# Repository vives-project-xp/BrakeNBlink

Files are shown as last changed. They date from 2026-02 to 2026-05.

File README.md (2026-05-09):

# BrakeNBlink
Brake N Blink is een (semi) automatisch rem en richtingaanwijzersysteem voor fietsen dat
de zichtbaarheid en veiligheid van fietsers verhoogt. Het detecteert automatisch via een IMU/Knoppen of de fietser remt/gaat afslaan en stuurt zo de remlichten en richtingaanwijzers aan.

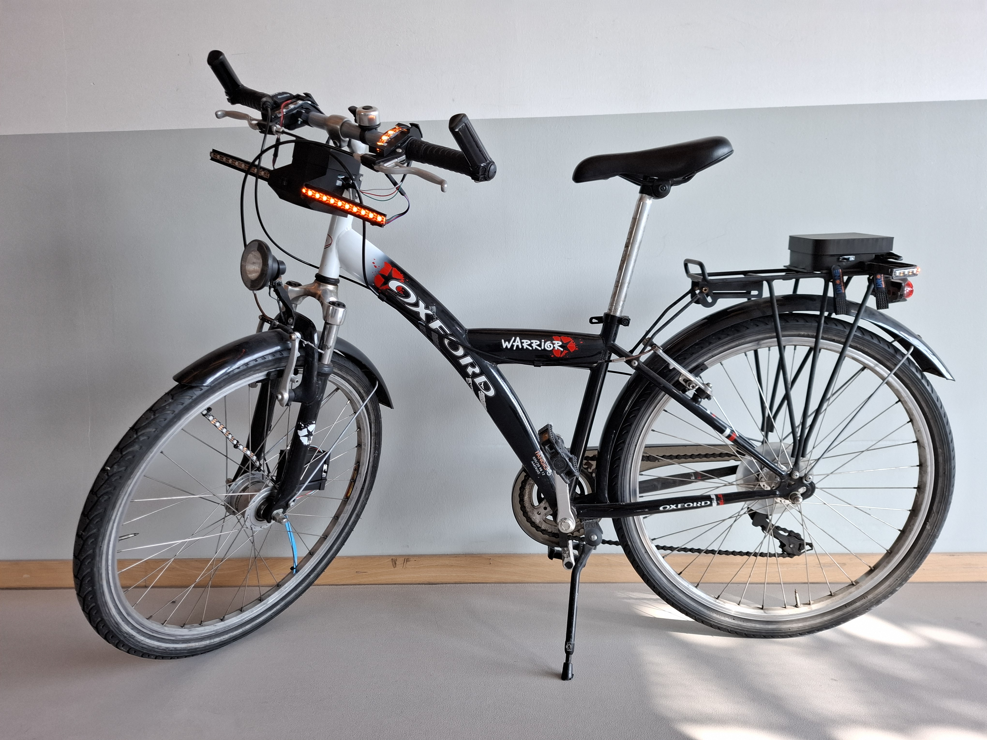
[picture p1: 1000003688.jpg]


---

## Doel van het project
Fietsers behoren tot kwetsbare weggebuikers, vooral in steden of omgevingen met een beperkte zichtbaarheid. Brake N Blink verhoogt de zichtbaarheid (zeker s'nachts) van de fietser voor andere weggebruikers.

---
## Product

### Vooraan
Drukknoppen voor de linker- en rechterrichtingaanwijzer, verbonden via Bluetooth met de achterste controlemodule. Eigen batterijvoorziening.

### Achteraan
Achteraan zit een microcontroller die het remlicht aanstuurt op basis van de interne IMU. De richtingaanwijzers worden bediend via een stuurmodule die draadloos verbonden is via Bluetooth.

### Uitbreiding
Led strips in de spaken via een microcontroller met interne batterij. Specifiek hebben we twee LED-strips tegenover elkaar gemonteerd op het voorwiel van de fiets. Deze strips produceren verschillende lichtpatronen, aangestuurd door een microcontroller, om de zichtbaarheid en esthetiek van de fiets te verbeteren.

### Gebruikershandleiding
Hier vindt u de [gebruikershandleiding](Documentatie/Gebruikershandleiding/) met instructies voor het gebruik en onderhoud van het BrakeNBlink-systeem.

---
## Project Management

Wij maken gebruik van Trello voor de sprintplanning en issue tracking.

---

## Reflectie

Tijdens dit project hebben we veel geleerd over het ontwerpen en implementeren van een elektronisch systeem voor fietsen. We hebben ervaring opgedaan met het gebruik van microcontrollers, Bluetooth-communicatie en het integreren van verschillende componenten zoals LED-strips en drukknoppen. We hebben ook geleerd hoe we een project kunnen structureren en documenteren, wat belangrijk is voor samenwerking en toekomstige referentie.

Hoewel we enkele uitdagingen tegenkwamen, zoals het optimaliseren van de Bluetooth-verbinding en het ontwerpen van een sterke en functionele behuizing. We hebben deze problemen opgelost door middel van trial and error. Al met al heeft dit project ons waardevolle vaardigheden en inzichten opgeleverd die we in toekomstige projecten kunnen toepassen.

---

## Repository structuur

- 📁 **[3D model behuizing/](3D%20model%20behuizing/)**: Bevat 3D-modellen voor de behuizing van het systeem, inclusief Blender-bestanden en 3MF-bestanden voor 3D-printing.
- 📁 **[Documentatie/](Documentatie/)**: Omvat alle documentatie gerelateerd aan het project.
  - 📁 **[Datasheets & Materiaal lijst/](Documentatie/Datasheets%20%26%20Materiaal%20lijst/)**: Datasheets, materiaaloverzichten en informatie over componenten zoals batterijhouders, bedrading, drukknoppen, LED-strips, microcontroller (Arduino), printplaten en batterijen.
  - 📁 **[Gids/](Documentatie/Gids/)**: Handleidingen, zoals de GitHub-gids.
  - 📁 **[Gebruikershandleiding/](Documentatie/Gebruikershandleiding/)**: Gebruikershandleiding voor het systeem.
  - 📁 **[Knoppen/](Documentatie/Knoppen/)**: Documentatie over de drukknoppen.
  - 📁 **[Overzichten/](Documentatie/Overzichten/)**: Overzichten van materialen, inclusief specifieke informatie over drukknoppen.
  - 📁 **[Voorstellingen/](Documentatie/Voorstellingen/)**: Sprekersnotities voor presentaties.
- 📁 **[Poster/](Poster/)**: Bevat de projectposter.
- 📁 **[Prototypes and simulations/](Prototypes%20and%20simulations/)**: Code en schema's voor prototypes en simulaties.
  - 📁 **[Eerste versie op breadboard/](Prototypes%20and%20simulations/Eerste%20versie%20op%20breadboard/)**: Eerste prototype op breadboard met Arduino-code.
  - 📁 **[Eindresultaat/](Prototypes%20and%20simulations/Eindresultaat/)**: Finale prototypes, inclusief LED-strips en normale LEDs met Bluetooth-functionaliteit.
  - 📁 **[Led strip Test/](Prototypes%20and%20simulations/Led%20strip%20Test/)**: Testcode voor LED-strips.
  - 📁 **[Prototype Gyro/](Prototypes%20and%20simulations/Prototype%20Gyro/)**: Prototype met gyroscoop.
  - 📁 **[Prototype Remlicht/](Prototypes%20and%20simulations/Prototype%20Remlicht/)**: Prototype voor remlicht.
  - 📁 **[Top Down Schema's/](Prototypes%20and%20simulations/Top%20Down%20Schema%27s/)**: Top-down schema's voor prototypes, master, slave en uitbreidingen.
  - 📁 **[Uitbreiding/](Prototypes%20and%20simulations/Uitbreiding/)**: Uitbreidingen voor het systeem, inclusief extra LEDs.
- 📁 **[Sociale media/](Sociale%20media/)**: Afbeeldingen en media voor sociale media, inclusief 3D-printing, prototypes op de fiets en solderen.

## Team
dit project is gemaakt door:

- **Tom Pladijs** - fase 2, Elektronica
- **Timo Sinnaeve** - fase 1, Elektronica ICT
- **Aaron Lestarquit** - fase 1, Elektronica ICT

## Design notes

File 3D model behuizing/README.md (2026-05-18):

# BrakeNBlink - 3D Modellering Behuizing

## Projectoverzicht

Dit project bevat de volledige 3D-modellering voor de behuizing van **BrakeNBlink**. De modellen zijn ontworpen in Blender en geoptimaliseerd voor 3D-printing. In de uitbreiding folder, vind je de bestanden voor de uitbreiding.

**BrakeNBlink** bestaat uit drie delen + uitbreiding:
- **Voorkant**: bevat de elektronica en richtingaanwijzers
- **Achterkant**: ook elektronica met richtingaanwijzers en achterlicht
- **Stuur**: knoppen om richtingaanwijzers aan te zetten met een korte richtingaanwijzer ledstrip.
- **Uitbreiding**: extra zichbaarheid aan het wiel

---

## Gebruikte modelling software

- **Blender** 4.3.2 - 3D modellering en design
- **Formaat**: .blend & .blend1 (Blender native format)
- **Export formaat**: .stl voor 3D-printing

---

## Mappenstructuur

```
3D model behuizing/
├── BrakeNBlink Behuizing.blend     # Blender hoofdbestand
├── README.md                          # Dit bestand
├── 3D Print Files/                    
│   ├── Voorkant/                      # Behuizing voorkaant
│   ├── Achterkant/                    # Behuizing achterkant
│   └── Stuur/                         # Behuizing op het stuur
│   └── README_3D_Print.md         # Print instellingen
└── Uitbreiding/                       # Deel aan het wiel
```

---

## Blender Bestandsstructuur
- afgemeten componenten: wordt gebruikt als referentie om de behuizing te maken.
- Assembly: montage van alles op de fiets, puur visueel
- Moddeling: hierin worden de behuizing aangepast en verbeterd
- Om te 3D printen: bestanden klaar voor export naar .stl


---

## 3D-Printbare Onderdelen

Alle printbare onderdelen bevinden zich in de `3D Print Files/` map. Elk onderdeel is afzonderlijk beschikbaar als `.stl`-bestand:

---

## Montage

---

### bestanden in Blender aanpassen:
1. Open `BrakeNBlink Behuizing.blend` in Blender
2. Selecteer de collectie die je wilt wijzigen
3. Maak de gewenste wijzigingen
4. Exporteer naar `.stl` via: **File > Export > .stl**

---

### Benodigde hardware voor installatie
- M4 bouten en moeren

---

## Ondersteuning & Opmerkingen

- Voor vragen over de modellering: raadpleeg het Blender-bestand
- Voor printinstellingen: zie `3D Print Files/README_3D_Print.md`

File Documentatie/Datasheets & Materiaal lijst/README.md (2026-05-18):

# BrakeNBlink — Architectuur Document

## 1. Projectoverzicht

BrakeNBlink is een semi-automatisch rem- en richtingaanwijzersysteem voor fietsen. Het systeem bestaat uit twee modules: een **achtermodule** (Peripheral) die remlichten en richtingaanwijzers aanstuurt, en een **stuurmodule** (Central) met drukknoppen voor de richtingaanwijzers. De twee modules communiceren draadloos via Bluetooth Low Energy (BLE).

Optioneel is er een **uitbreidingsmodule** met LED-strips in de spaken van het wiel.

---

## 2. Systeemoverzicht

```
[ Stuurmodule (Central) ]
   - Arduino Nano 33 BLE Sense Rev2
   - 2x Drukknop
   - 2x LED strip (richtingaanwijzer links/rechts)
   - Batterij (3 x AAA)
          |
          | Bluetooth Low Energy (BLE)
          |
[ Achtermodule (Peripheral) ]
   - Arduino Nano 33 BLE Sense Rev2
   - IMU ingebouwd (BMI270 + BMM150)
   - 3x LED strip (links / rechts / rem)
   - Batterij (3 x AAA)

[ Uitbreidingsmodule (optioneel) ]
   - Arduino Nano 33 BLE Sense Rev2
   - 2x LED strip (spaken)
   - IMU (snelheidsmeter)
   - Batterij (3 x AA)
```

---

## 3. Componenten

### 3.1 Microcontroller — Arduino Nano 33 BLE Sense Rev2

| Eigenschap | Waarde |
|---|---|
| Voedingsspanning | 3.3 V (logica) / 5 V (USB / VIN) |
| Max stroom per I/O pin | 15 mA |
| Aanbevolen VIN | 5 – 21 V |
| BLE | Bluetooth 5.0 |
| IMU | BMI270 (accel/gyro) + BMM150 (mag)  |
| Afmetingen | 45 × 18 mm |
| Verbruik actief | 60 mA |
| Verbruik BLE actief | 70 mA |
| Max vermogen | 0.35 W |

> Wordt gebruikt in: Stuurmodule (Central), Achtermodule (Peripheral) en Uitbreidingsmodule.

---

### 3.2 LED Strip — SK6812 RGBW

| Eigenschap | Waarde |
|---|---|
| Voedingsspanning | 5 V DC |
| Stroom per LED (volledig)| 80 mA |
| Max stroom (16 LEDs) | 1280 mA |
| Max vermogen (16 LEDs) | 6.4 W |
| Kleur | RGB + Natuurlijk Wit |
| Waterdichtheid | IP65 |
| Dataprotocol | NeoPixel (800 kHz) |
| Logicaspanning data | 5 V (3.3 V compatibel via niveau-omzetter) |

**Aansluitingen:**

| Strip-pin | Kleur draad | Aansluiting |
|---|---|---|
| 5V / VCC  | Rood | 5 V (via BEC of externe voeding) |
| GND | Wit | GND |
| DIN | Groen | Digitale pin Arduino (zie module) |
| DO | — | DIN van de volgende LED / strip |

> Elke LED geeft de resterende data door via DO → DIN van de volgende LED.

---

### 3.3 Drukknop (2-pin mechanisch)

| Eigenschap | Waarde |
|---|---|
| Type | Mechanische drukknop, 2-pin |
| Standaard toestand | HOOG (INPUT_PULLUP actief) |
| Ingedrukt | Verbonden met GND → LAAG |
| Max spanning | 12 V |
| Max stroom | 100 mA |
| Debounce tijd (code) | 150 ms |

**Aansluitingen:**

| Knop-pin | Aansluiting Arduino |
|---|---|
| Pin 1 | GND |
| Pin 2 | Digitale pin (D2 of D3) met INPUT_PULLUP |

---

### 3.4.1 Batterij — 3 × AAA 

| Eigenschap | Stuurmodule | Achtermodule |
|---|---|---|
| Aantal cellen | 3 × AAA | 3 × AAA |
| Nominale spanning | 4.5 V | 4.5 V |
| Capaciteit | 3000 mAh | 3000 mAh | 
| Max ontlaadstroom | 1.5 A | 1.5 A |

### 3.4.2 Batterij — 3 × AA 

| Eigenschap | Uitbreidingsmodule |
|---|---|
| Aantal cellen | 3 × AA |
| Nominale spanning | 4.5 V |
| Capaciteit | 2400 mAh |

---

### 3.5 Verbindingskabel — JST-SM 3-pin Verlengkabel

| Eigenschap | Waarde |
|---|---|
| Lengte | 30 cm |
| Pinnen | 3 |
| Type | JST-SM Compatibel |
| Gebruik | Aansluiting batterijhouder |

---

## 4. Pin-mapping per module

### 4.1 Stuurmodule (Central) — Arduino Nano 33 BLE Sense Rev2

| Pin | Functie | Component |
|-----|---|---|
| D2  | Knop Links (INPUT_PULLUP) | Drukknop Links |
| D3  | Knop Rechts (INPUT_PULLUP) | Drukknop Rechts |
| D4  | LED strip Links (DIN) | SK6812 strip Links |
| D5  | LED strip Rechts (DIN) | SK6812 strip Rechts |
| 5V  | Voeding LED strips | SK6812 via BEC / extern |
| GND | Ground | Alle componenten |
| VIN | Voeding vanuit batterij | Batterijhouder |

> BLE rol: **Central** — scant en verbindt met de Peripheral.

---

### 4.2 Achtermodule (Peripheral) — Arduino Nano 33 BLE Sense Rev2

| Pin | Functie | Component |
|---|---|---|
| D2 | LED strip Links (DIN) | SK6812 strip Links |
| D3 | LED strip Rechts (DIN) | SK6812 strip Rechts |
| D4 | LED strip Remlicht (DIN) | SK6812 strip Remlicht |
| IMU intern  | Versnellingsmeting X-as (ax) | BMI270 (ingebouwd) |
| IMU intern  | Kantelmeting lean angle (by, bz)  | BMI270 (ingebouwd) |
| 5V | Voeding LED strips | SK6812 via BEC / extern |
| GND | Ground | Alle componenten |
| VIN | Voeding vanuit batterij | Batterijhouder |

> BLE rol: **Peripheral** — adverteert als `"Nano 33 BLE Peripheral"`.  
> IMU drempel remmen: `ax < -0.20 g` → remlicht aan.  
> IMU drempel blinker auto-uit: kanteling `> 10°`, terugkeer `< 2°`.

---

### 4.3 Uitbreidingsmodule (spaken) — Arduino Nano 33 BLE Sense Rev2

| Pin | Functie | Component |
|---|---|---|
| D2 | LED strip A (DIN) | SK6812 strip Spaak A |
| D3 | LED strip B (DIN) | SK6812 strip Spaak B |
| IMU intern | Snelheidsmeting | BMI270 (ingebouwd) |
| 5V | Voeding LED strips | SK6812 via extern |
| GND | Ground | Alle componenten |
| VIN | Voeding vanuit batterij | Eigen batterij |

---

## 5. Bluetooth communicatie

| Eigenschap | Waarde |
|---|---|
| Protocol | Bluetooth Low Energy (BLE 5.0) |
| Service UUID | `19b10000-e8f2-537e-4f6c-d104768a1214` |
| Characteristic UUID  | `19b10001-e8f2-537e-4f6c-d104768a1214` |
| Peripheral naam | `"Nano 33 BLE Peripheral"` |
| Datatype | Byte (1 byte per commando) |

**Stuurcommando's (byte-waarden):**

| Byte waarde | Actie |
|---|---|
| `1` | Toggle linker richtingaanwijzer |
| `3` | Toggle rechter richtingaanwijzer |

---

## 6. Vermogensverdeling & elektriciteitsbudget

### 6.1 Stuurmodule

| Component | Spanning (V) | Stroom (mA) | Vermogen (W) |
|---|---|---|---|
| Arduino Nano 33 BLE | 3.3 / 5 | 65 | 0.21 |
| LED strip Links (16×) | 5 | 1280 | 6.4 |
| LED strip Rechts (16×)  | 5 | 1280 | 6.4 |
| Drukknop Links | 3.3 | ≈ 0 | ≈ 0 |
| Drukknop Rechts | 3.3 | ≈ 0 | ≈ 0 |
| **Totaal** | | 2625 | 13.01 |

### 6.2 Achtermodule

| Component | Spanning (V) | Stroom (mA) | Vermogen (W) |
|---|---|---|---|
| Arduino Nano 33 BLE | 3.3 / 5 | 65 | 0.21 |
| LED strip Links (16×) | 5 | 1280 | 6.4 |
| LED strip Rechts (16×)  | 5 | 1280 | 6.4 |
| LED strip Rem (16×) | 5 | 1280 | 6.4 |
| **Totaal** | | 3905 | 19.41 |

### 6.3 Uitbreidingsmodule

| Component | Spanning (V) | Stroom (mA) | Vermogen (W) |
|---|---|---|---|
| Arduino Nano 33 BLE | 3.3 / 5 | 65 | 0.21 |
| LED strip A (16×) | 5 | 1280 | 6.4 |
| LED strip B (16×) | 5 | 1280 | 6.4 |
| **Totaal** | | 2625 | 12.81 |

---

## 7. Softwarebiblioteken

| Bibliotheek | Versie | Gebruik |
|---|---|---|
| ArduinoBLE | 1.2.0 | Bluetooth Low Energy communicatie |
| Adafruit NeoPixel | 1.10.0 | SK6812 LED strip aansturing |
| Arduino_BMI270_BMM150  | 1.0.2 | IMU (accelerometer / gyroscoop) |

---

## 8. IMU logica

### Remdetectie (Achtermodule)
| Parameter | Waarde |
|---|---|
| Gemeten as | Lineaire versnelling X-as (ax)  |
| Drempelwaarde | `ax < -0.20 g` |
| Actie | Remlicht aan (rood) |
| Updatefrequentie  | Elke 10 ms |

### Richtingaanwijzer automatisch uit (Achtermodule)
| Parameter | Waarde |
|---|---|
| Berekening | `leanAngle = abs(atan2(by, bz) × 180 / π)` |
| Bocht gedetecteerd | `leanAngle > 10°` |
| Bocht voltooid | `leanAngle < 2°` (nadat de fiets geleund was)  |
| Actie | Blinker automatisch uit, LEDs uit |

---

## 9. Gedragsoverzicht

| Situatie | Actie systeem |
|---|---|
| Fietser remt | IMU detecteert vertraging → remlicht aan (rood) |
| Knop links ingedrukt | Linker LED strip knippert oranje (500 ms interval) |
| Knop links opnieuw ingedrukt | Linker richtingaanwijzer uit |
| Knop rechts ingedrukt | Rechter LED strip knippert oranje |
| Bocht voltooid (lean detected) | Blinker automatisch uit |
| Geen Bluetooth verbinding | Verbindings-LED uit, herverbinding automatisch |

---

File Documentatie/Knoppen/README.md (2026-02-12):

# Knoppen

2 knoppen zijn gemonteerd op het stuur van de fiets (links en rechts) en worden gebruikt om de richtingaanwijzers aan te sturen. De fietser klikt op een van de knoppen kort waardoor die richtingaanwijzer aan gaat. Ze gaan automatisch uit als de fiets weer rechtdoor rijdt of als er een tweede keer word geklikt. 

# Type knoppen:

## 1. 2-pin knoppen


Dit zijn mechanische knoppen met 2 pins:
- als je niks doet -> circuit is open
- als je klikt -> twee pins zijn verbonden

Standaard staat die op HOOG, als je klikt komt het circuit in verbinding met de GND, waardoor het op LAAG staat.

Wiring van een 2 pin knop:
- Pin 1: GND
- Pin 2: Digitale pin (bv. D2)

Nadeel van 2-pin knoppen: ze switchen niet mooi, niet waterdicht en wanneer er gedrukt wordt, gaan ze open en dicht heel snel voor een paar milliseconden. Dit wordt "bounce" genoemd. Hierdoor kan het zijn dat er meerdere keren "geklikt" wordt. Om dit te fixen kan je best een kleine delay toevoegen met wanneer de laatste keer geklikt werd.

## 2. Tactile push knoppen


Dezelfde werking als 2-pin knoppen, als je erop klikt is het circuit verbonden. Standaard staat die op HOOG, als je klikt komt het circuit in verbinding met de GND, waardoor het op LAAG staat. Het heeft 4 pins:
- Pin 1 en Pin 3 zijn intern verbonden
- Pin 2 en Pin 4 zijn intern verbonden

Wiring van Tactile knop:
- Pin 1 → GND
- Pin 2 → D2
- Pin 3 → niet verbonden
- Pin 4 → niet verbonden

Nadelen:  Niet goed voor vibraties en vaak ook niet waterdicht. 

# 3. SPDT center off switch / slide switch SPDT


een 3 switch knop, waarbij er 3 mogelijk positie's zijn. links, midden en rechts. Wordt gebruikt op de meeste motors en dus daardoor bekend. Handig als de fietser de button naar een kant duwt voor bv. de linkerrichtingaanwijzers aan te steken. Er kan altijd maar 1 richtingaanwijzer aan en de fietser kan zelf kiezen om het te stoppen. LOW -> Active

Layout:
- Links - Midden (uit) - Rechts

Wiring:
- Links -> 1ste digitale pin (Bv. D1)
- Common -> GND
- Rechts -> 2de digitale pin (Bv. D2)

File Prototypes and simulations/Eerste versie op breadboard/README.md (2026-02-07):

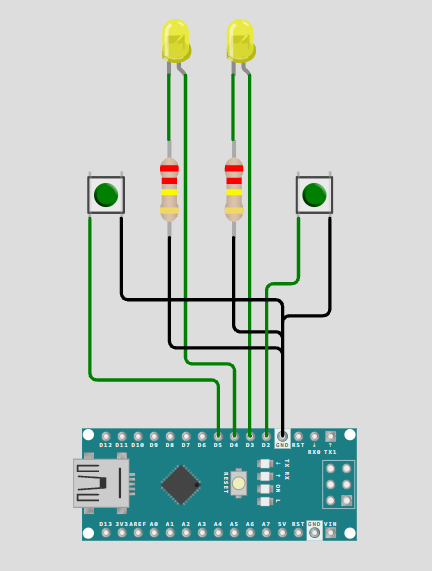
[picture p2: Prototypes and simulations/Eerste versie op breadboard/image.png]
Arduino nano 2 leds

---
const int led1 = 3;
const int led2 = 4;

const int button1 = 2;
const int button2 = 5;

bool led1State = false;
bool led2State = false;

bool lastButton1 = HIGH;
bool lastButton2 = HIGH;

void setup() {
  pinMode(led1, OUTPUT);
  pinMode(led2, OUTPUT);

  pinMode(button1, INPUT_PULLUP);
  pinMode(button2, INPUT_PULLUP);
}

void loop() {
  bool currentButton1 = digitalRead(button1);
  bool currentButton2 = digitalRead(button2);

  // --- Toggle LED 1 ---
  if (lastButton1 == HIGH && currentButton1 == LOW) {
    led1State = !led1State;          // wissel aan/uit
    digitalWrite(led1, led1State);
    delay(200);                      // simpele debounce
  }
  lastButton1 = currentButton1;

  // --- Toggle LED 2 ---
  if (lastButton2 == HIGH && currentButton2 == LOW) {
    led2State = !led2State;
    digitalWrite(led2, led2State);
    delay(200);
  }
  lastButton2 = currentButton2;
}

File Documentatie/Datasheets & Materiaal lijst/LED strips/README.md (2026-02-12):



LED SK8612 RGBW LED Strip

# specificaties:
- Voltage: DC5V
- IP65 Waterdicht
- Kleur: RGB + Natuurlijk wit
- Verbinding: VCC: rood, GND: Wit, DAT: groen

# Pads betekenis:

- 5V: Power for the LEDs
- GND: Ground
- DIN: Data IN (van de microcontroller)
- DO: Data OUT (naar het volgende LED / strip)
- Each LED passes the remaining data from DO → next LED’s DIN

| Pin | Arduino |
|---|---|
| 5V | 5V (van een BEC) |
| DIN/DOUT | Digitale pin (bv. D6)  |
| GND | GND |

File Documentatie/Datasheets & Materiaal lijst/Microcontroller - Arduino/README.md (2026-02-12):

# Developer Environment
Als developer environment maken we gebruik van Arduino IDE. Installatielink: https://www.arduino.cc/en/software/

Na het installeren moet er in de IDE zelf nog een package geïnstalleerd worden.

INSTALL-BLE-SENSE-REV2-IDE

# Arduino PIN OUT



# Arduino links
IMU uitleg: https://docs.arduino.cc/tutorials/nano-33-ble-sense-rev2/imu-accelerometer/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

Bluetooth uitleg: https://docs.arduino.cc/tutorials/nano-33-ble-sense/ble-device-to-device/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

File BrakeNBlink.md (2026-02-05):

# BrakeNBlink
Brake N Blink is een (semi) automatisch rem en richtingaanwijzersysteem voor fietsen dat
de zichtbaarheid en veiligheid van fietsers verhoogt. Het detecteert automatisch via een IMU/Knoppen of de fietser remt/gaat afslaan en stuurt zo de remlichten en richtingaanwijzers aan.

---

## Doel van het project
Fietser behoren zijn kwetsbare weggebuikers, vooral in steden of omgevingen met een beperkte zichtbaarheid. Brake N Blink verhoogt de zichtbaarheid (zeker s'nachts) van de fietser voor andere weggebruikers

---
## Idee

### Basis
Achteraan zit een microcontroller die de remlichten aanstuurt op basis van een interne IMU. De richtingaanwijzers worden bediend via een stuurmodule die draadloos verbonden is via Bluetooth.

### Vooraan
Drukknoppen voor de linker- en rechterrichtingaanwijzer, verbonden via Bluetooth met de achterste controlemodule. Eigen batterijvoorziening.

---

## Repository structuur

---

## Team
dit project is gemaakt door:

- **Tom Pladijs** - fase 2, Elektronica
- **Owen Bruneel** - fase 1, Elektronica ICT
- **Timo Sinnaeve** - fase 1, Elektronica ICT
- **Aaron Lestarquit** - fase 1, Elektronica ICT
- **Adonai Brouwers** - fase 1, Elektronica ICT

## Uitbreiding

Tekstweergave in de spaken via een microcontroller met interne batterij.

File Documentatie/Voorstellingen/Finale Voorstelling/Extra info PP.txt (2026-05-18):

remote: error: Trace: b9c62019eaaad30f973fd03236cbd765a5ce48beb432659b158a3819029bced2
remote: error: See https://gh.io/lfs for more information.
remote: error: File Documentatie/Voorstellingen/Finale Voorstelling/Presentatie BrakeNBlink_V2.pptx is 236.62 MB; this exceeds GitHub's file size limit of 100.00 MB
remote: error: File Documentatie/Voorstellingen/Finale Voorstelling/Foto's/Wiiel.gif is 121.44 MB; this exceeds GitHub's file size limit of 100.00 MB
remote: error: GH001: Large files detected. You may want to try Git Large File Storage - https://git-lfs.github.com.

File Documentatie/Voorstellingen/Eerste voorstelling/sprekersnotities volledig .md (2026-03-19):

🎯 Kernboodschap

Brakenblink is een slimme fietsreflector die fietsers zichtbaarder, veiliger en voorspelbaarder maakt in het verkeer dankzij een geïntegreerd remlicht, richtingsaanwijzers, en toekomstige uitbreidingen zoals spaken‑LED’s.

🧩 1. Intro: het probleem dat we oplossen

Fietsers zijn vaak slecht zichtbaar, vooral in het donker of bij regen.

Klassieke reflectoren en standaardverlichting geven geen informatie over intentie: je ziet niet wanneer iemand remt of afslaat.

Auto’s hebben al decennia remlichten en richtingaanwijzers. Fietsers niet — terwijl zij kwetsbaarder zijn.

→ Brakenblink vult precies dat gat.

🚲 2. Wat is Brakenblink?

Een slimme fietsreflector die meer doet dan reflecteren.

Integreert remlicht, richtingaanwijzers en aandachtsverlichting in één compact systeem.

Gebruikt de interne gyroscoop om bewegingen te detecteren (remmen, vertragen, sturen).

Communiceert via BLE (Bluetooth Low Energy) voor koppeling met een app of afstandsbediening.

→ Het resultaat: een fiets die communiceert zoals een auto, zonder dat de fietser extra handelingen moet doen.

🛠️ 3. Wat hebben we vandaag al gerealiseerd?

Een werkend prototype dat de basisfunctionaliteit simuleert:

remdetectie

richtingaanwijzers

basislogica van de gyro

3D‑renders van de volledige montage en behuizing.

Een top‑down schema van de elektronische opstelling:

microcontroller

gyro

LED‑drivers

BLE‑module

voeding

Alle bestellingen zijn geplaatst voor de componenten die we nodig hebben om de volgende iteratie te bouwen.

→ We staan niet aan het begin van een idee, maar midden in de realisatie.

💡 4. De technologie achter Brakenblink

Gyroscoop: detecteert vertraging → activeert remlicht automatisch.

BLE: maakt koppeling mogelijk met een stuurknop, smartphone of toekomstige accessoires.

Modulaire LED‑aansturing: laat ons uitbreiden zonder het systeem te herontwerpen.

Energie‑efficiënt ontwerp: gericht op lange batterijduur en minimale onderhoud.

🌟 5. Toekomstige uitbreiding: LED‑strip in de spaken

Een 360° aandachtsverlichting die de fiets nog zichtbaarder maakt vanuit alle hoeken.

Dynamische patronen mogelijk (bijv. pulseren bij remmen).

Verhoogt de herkenbaarheid van de fietser in stadsverkeer.

Perfect voor zowel veiligheid als esthetiek.

→ Dit maakt Brakenblink niet alleen functioneel, maar ook opvallend en modern.

🚀 6. Waarom dit relevant is

Verkeersveiligheid voor fietsers is een groeiend maatschappelijk thema.

Slimme mobiliteit is in opmars — maar fietsen blijven achter.

Brakenblink is betaalbaar, licht, slim, en direct toepasbaar op elke fiets.

Het systeem is schaalbaar: van basisreflector tot volledig smart‑lighting‑ecosysteem.

🔚 7. Afsluitende boodschap

Brakenblink is meer dan een gadget. Het is een stap richting slimmere, veiligere en mensvriendelijke mobiliteit.

We hebben de technologie, het prototype, de visuals en de componenten klaar.

De volgende stap is bouwen, testen en opschalen.

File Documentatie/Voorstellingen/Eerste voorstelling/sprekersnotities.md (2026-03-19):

🟧 Spiekbriefje Brakenblink – alle punten die je moet zeggen

🔸 Wat is Brakenblink?

Slimme fietsreflector

Integreerd remlicht + richtingsaanwijzers

Doel: meer zichtbaarheid en duidelijkere intentie van de fietser

🔸 Technologie

Gebruikt interne gyroscoop → detecteert remmen \& beweging

BLE‑connectie voor koppeling met app/bediening

Energiezuinig ontwerp

🔸 Waarom dit nodig is

Fietsers zijn kwetsbaar

Klassieke verlichting toont geen intentie

Auto’s hebben remlichten en richtingaanwijzers → fietsen nog niet

Brakenblink vult die veiligheidskloof

🔸 Wat we al hebben

Werkend prototype dat basiswerking simuleert

3D‑renders van montage en behuizing

Top‑down schema van de elektronische opstelling

Alle bestellingen geplaatst voor de volgende bouwfase

🔸 Hoe het werkt

Gyro detecteert vertraging → remlicht

Richtingsaanwijzers via logica of bediening

Modulaire LED‑aansturing → makkelijk uitbreidbaar

🔸 Toekomstige uitbreiding

LED‑strip in de spaken

360° zichtbaarheid

Extra aandachtsverlichting

Mogelijke dynamische patronen

🔸 Waarom Brakenblink sterk staat

Veiligheid + zichtbaarheid + modern design

Slimme mobiliteit voor fietsen

Schaalbaar systeem (basisreflector → volledig smart‑ecosysteem)

🔸 Afsluiter

We hebben idee → prototype → visuals → componenten

Klaar voor bouwen, testen en opschalen

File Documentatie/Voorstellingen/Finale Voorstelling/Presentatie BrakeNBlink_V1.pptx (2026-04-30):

## Brake N’Blink

- Aaron Lestarquit -fase 1, Elektronica ICT
- Timo Sinnaeve - fase 1, Elektronica ICT
- Tom Pladijs - fase 2, Elektronica

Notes: 1. Titelpagina
Titel: Braken n Blink – Slim Fietslicht & Remsysteem
Ondertitel: Innovatieve veiligheid voor fietsers
Naam, klas, datum
Eventueel een foto/visual van een fietslicht

## Dagelijkse uitdagingen

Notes: 3. Wat is Brake n Blink?
Slim fietslicht met geïntegreerde remdetectie
Automatische richtingaanwijzers
Trillings- en bewegingssensoren
Draadloze communicatie tussen modules
Ontworpen voor maximale zichtbaarheid en veiligheid

## Fietsbestuurders

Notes: 2. Inleiding: Het Probleem
Toenemende fietsers → meer ongevallen

## Onzichtbaarheid

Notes: 2. Inleiding: Het Probleem
Fietsers worden vaak niet gezien bij remmen of afslaan
Klassieke fietslichten geven geen remsignaal
Nood aan slimme, automatische veiligheidssystemen
Doel van de presentatie: tonen hoe Braken n Blink dit oplost

## Onzichtbaarheid

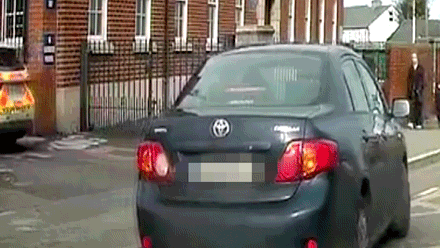
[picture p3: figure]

## Wat is Brake n Blink

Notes: 3. Wat is Brake n Blink?
Slim fietslicht met geïntegreerde remdetectie
richtingaanwijzers
bewegingssensoren
Draadloze communicatie tussen modules
Ontworpen voor maximale zichtbaarheid en veiligheid

## remsysteem

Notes: 5. Hoe werkt het remsysteem?
Versnellingssensor (accelerometer) meet plots vertragen
Microcontroller analyseert data
LED’s schakelen automatisch naar fel rood remlicht
Reageert binnen milliseconden

## Richtingaanwijzers

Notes: 6. Hoe werkt het richtingaanwijzersysteem?
Gyroscoop detecteert stuurbeweging
Of: knopje op stuur (afhankelijk van jouw ontwerp)
LED’s knipperen links of rechts
Duidelijke, heldere amberkleurige knipperlichten
Automatische uitschakeling na de bocht (optioneel)

## Hardware-overzicht

Microcontroller Arduino Nano
LED
Batterij Systeem
Behuizing (3D‑print)
Draadloze verbinding (Bluetooth / RF)
accelerometer

## Microcontroller

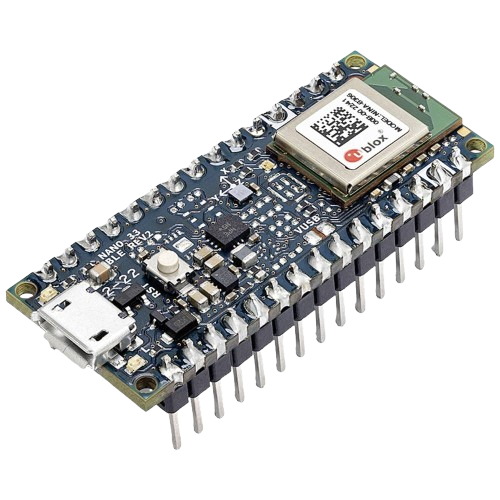
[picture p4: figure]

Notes: Arduino Nano BLE

## draadloze verbinding (uitleg kort via programma)

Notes: TIMO

## Accelerometer (uitleg kort via programma)

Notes: TIMO ( deze was te gevoelig ingesteld)

## Flow chart programma

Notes: TIMO

## LED

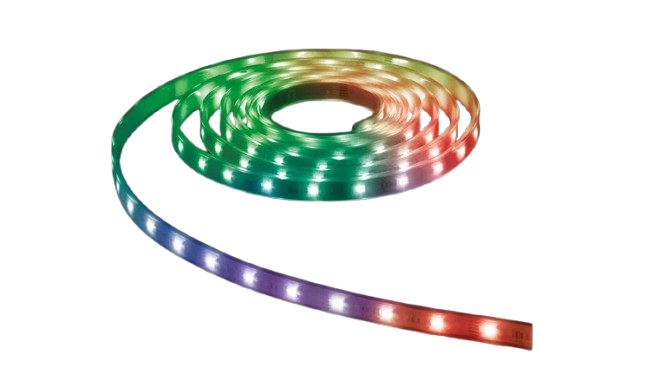
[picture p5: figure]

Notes: Probleem
Origineel was er een probleem dat we de led stips niet werkende kregen. Deze hadden we voor ons project ontvangen, na het switchen naar nieuwe leds waren alle problemen verdwenen
De richting verkeerd gesoldeerd

## Batterij

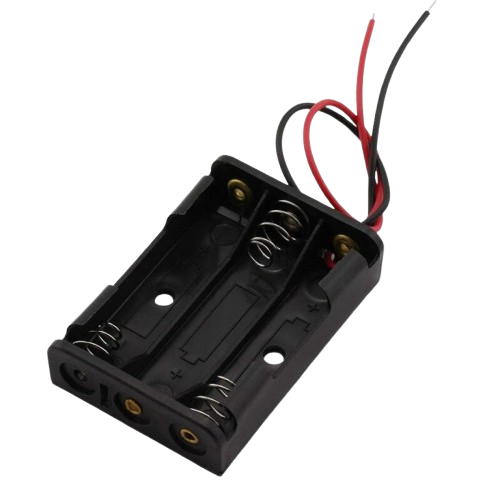
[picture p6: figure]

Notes: We werken met 2 x 3 AAA batterijen & 1 x 3AA

## Behuizing 3D‑print overzicht

- Slides Nog toe te voegen

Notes: TOM

## Top Down Schema Master ( nog recente versie toe te voegen)

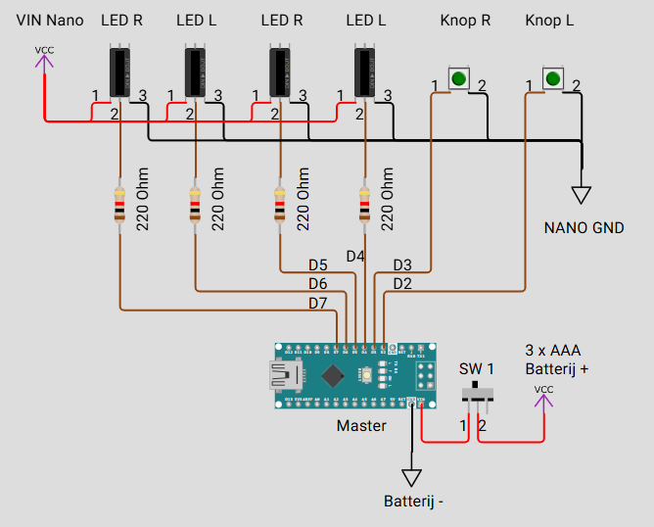
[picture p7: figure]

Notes: Top Down Schema ( nog recente versie toe te voegen)

## Top Down Schema Slave ( nog recente versie toe te voegen)

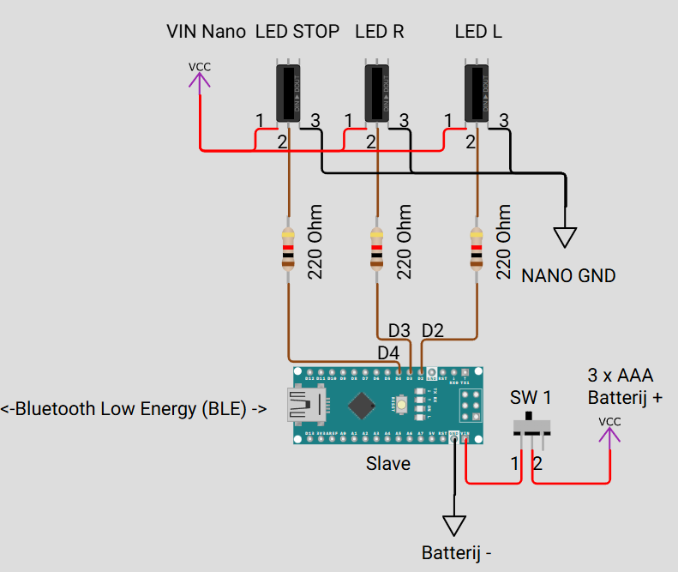
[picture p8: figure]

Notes: Top Down Schema ( nog recente versie toe te voegen)

## Top Down Schema Uitbreiding ( nog recente versie toe te voegen)

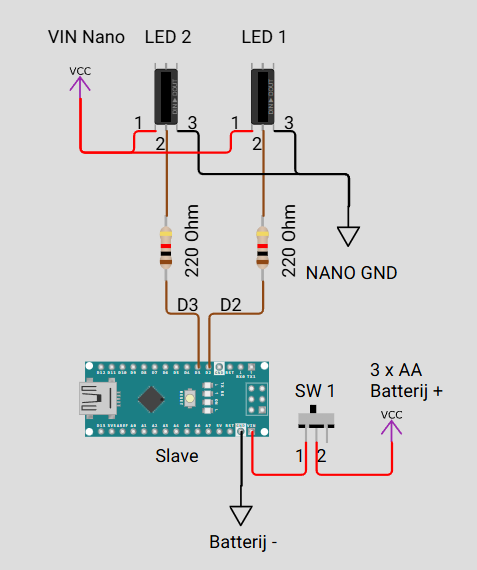
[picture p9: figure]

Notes: Top Down Schema ( nog recente versie toe te voegen)

## BrakeN’Blink

Zie en wordt gezien

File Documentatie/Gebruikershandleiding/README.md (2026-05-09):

# BrakeNBlink - Gebruikershandleiding

## Installatie-instructies

Volg de onderstaande stappen om het BrakeNBlink-systeem op uw fiets te monteren:

### Stap 1: Bevestig de behuizing aan de voorkant

Bevestig de behuizing aan de voorkant van de fiets met behulp van de bijgeleverde vijzen. Zorg ervoor dat de behuizing stevig vastzit rond de verticale metalen bar van het stuur.

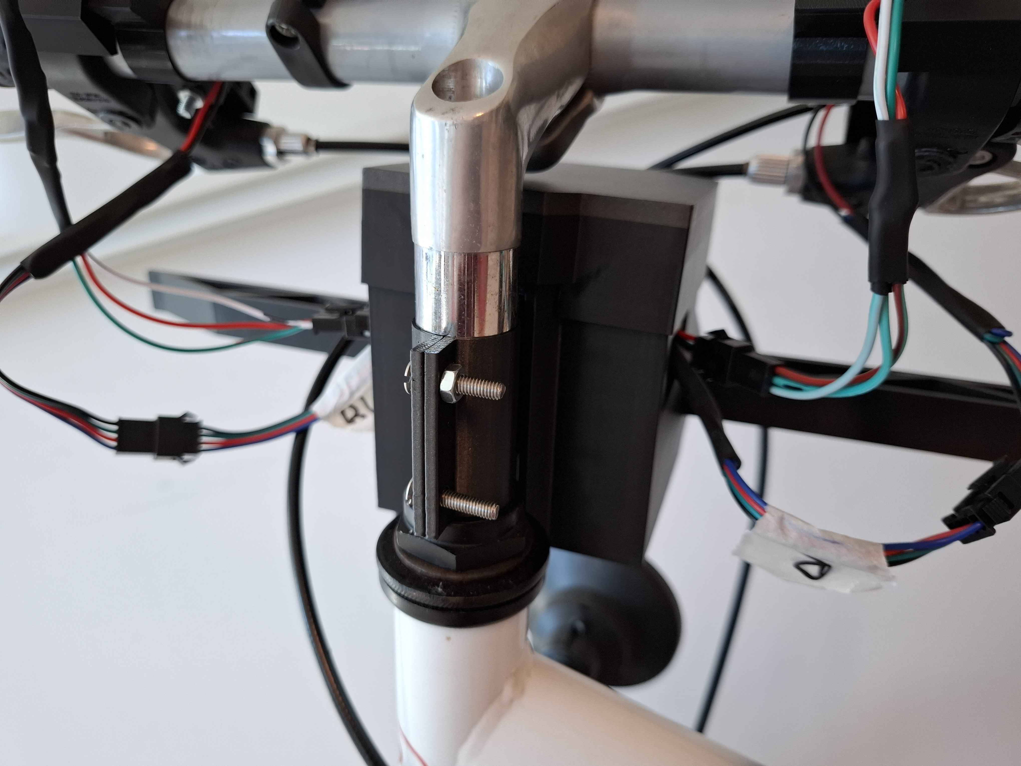
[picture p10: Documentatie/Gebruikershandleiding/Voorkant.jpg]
Voorkant behuizing


### Stap 2: Monteer de zijdelen op het stuur

Monteer de 2 delen aan het stuur en bevestig elk deel met 1 vijs. Zorg voor een stabiele en veilige bevestiging.

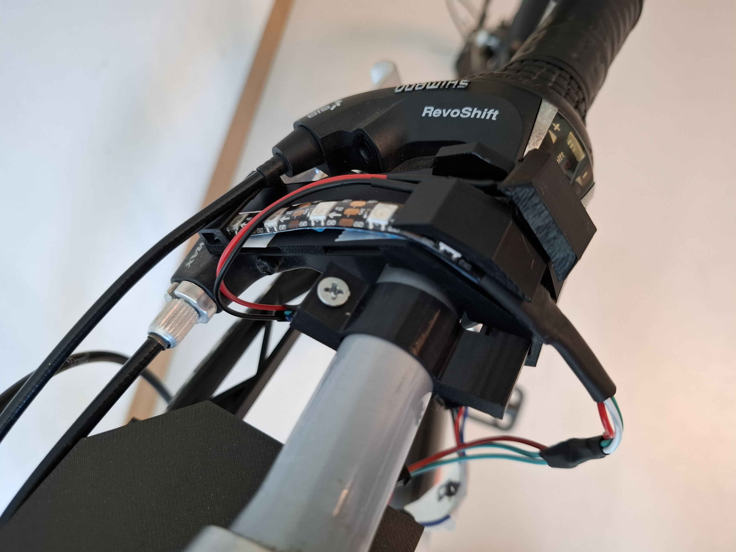
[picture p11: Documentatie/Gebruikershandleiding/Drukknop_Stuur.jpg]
Drukknoppen op stuur


### Stap 3: Bevestig de achterkant

Bevestig de achterkant van het systeem met behulp van 4 velcro straps. Zorg dat deze goed vastzitten om te voorkomen dat het systeem losraakt tijdens het fietsen.

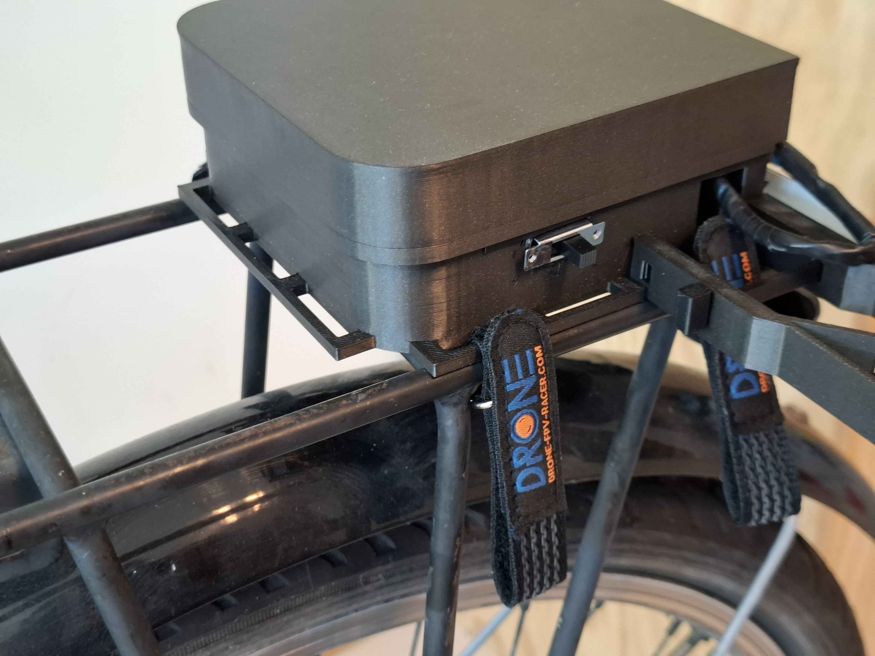
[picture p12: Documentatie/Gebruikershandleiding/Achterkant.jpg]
Achterkant


### Stap 4: Activeer de schuifknoppen

Schakel de schakelaars in om het systeem te activeren. De schakelaars zitten aan de linkerkant van beide behuizingen.

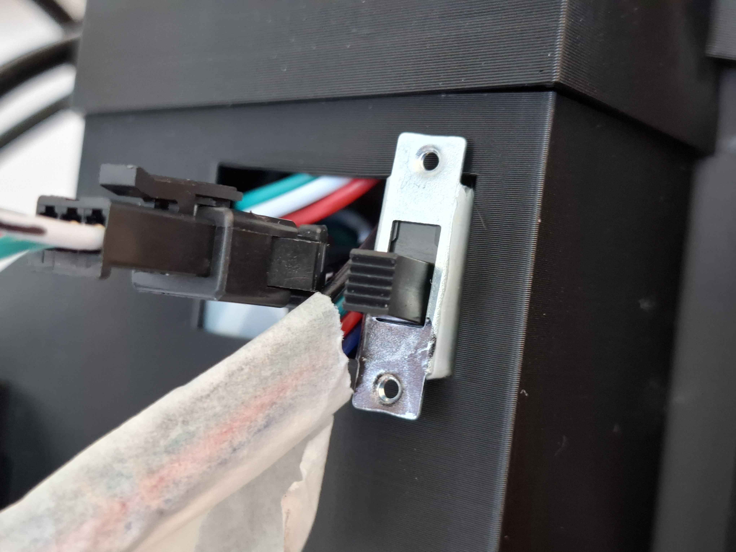
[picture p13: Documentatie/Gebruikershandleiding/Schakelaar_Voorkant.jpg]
Schakelaar voorkant

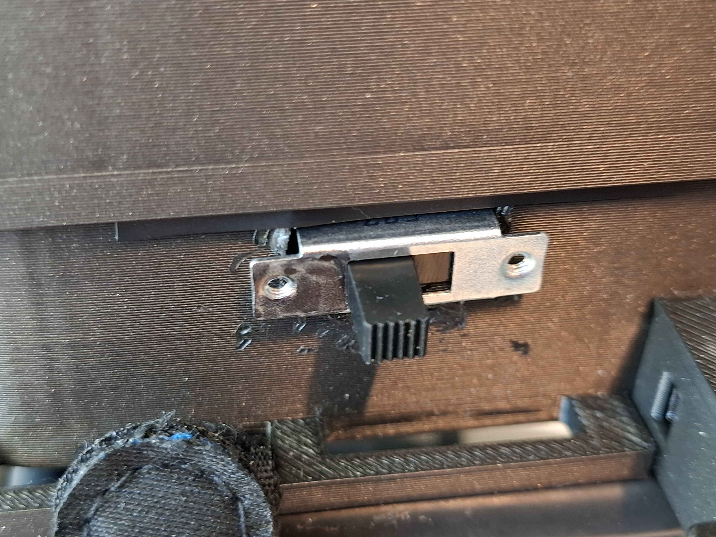
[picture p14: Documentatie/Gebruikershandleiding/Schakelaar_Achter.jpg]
Schakelaar achterkant


---

**Let op:** De zwarte kant van de schakelaar is de "aankant".

---

## Gebruikershandleiding

### Voor gebruik

- Zorg ervoor dat beide handen op het stuur blijven tijdens het gebruik van het BrakeNBlink systeem.

### Richtingsaanwijzers gebruiken

- **Linkerrichtingsaanwijzer:** Druk de linkerknop op het stuur in om de linkerrichtingsaanwijzer in te schakelen.
- **Rechterrichtingsaanwijzer:** Druk de rechterknop op het stuur in om de rechterrichtingsaanwijzer in te schakelen.
- **Uitschakelen:** Druk dezelfde knop opnieuw in om de richtingsaanwijzer uit te schakelen.

### Remlicht

Het remlicht gaat automatisch aan wanneer u remt.

---

## Veiligheidsinstructies

- Controleer regelmatig of alle bevestigingen nog stevig vastzitten.
- Gebruik het systeem niet bij hevige regen of extreme weersomstandigheden.
- Raadpleeg bij twijfel een lid van het BrakeNBlink team.

## Onderhoud

- We hebben voor de voorkant en de achterkant elk 3 AAA batterijen gebruikt. Voor de uitbreiding zijn dit 3 AA batterijen.
- Als de batterijen leeg zijn, haal dan het deksel van de behuizing en verwijder de batterijen. Vervang ze door nieuwe batterijen van hetzelfde type of laad de batterijen op.

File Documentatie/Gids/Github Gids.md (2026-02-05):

Alle commands worden in de windows terminal uitgevoerd, in de folder waarin je github repo staat.

## **Basis**
onze repository clonen op een folder lokaal:
```bash
git clone git@github.com:vives-project-xp/BrakeNBlink.git
```
### **Commit & Push**
Voodat je pushed, altijd eerst de content pullen:
```bash
git pull
```

Files toevoegen, commiten en pushen:
```bash
git add .
git commit -m "een bericht met de veranderingen dat je hebt gemaakt"
git push 
```
als **git push** niet werkt, probeer:
```bash
git push origin main
```

### **Check je status (eventuele aanpassingen dat er zijn gemaakt, puur informatief):**
```bash
git status
```

### **Merge conflicten**
een merge conflict is wanneer twee personen een verandering hebben gemaakt aan dezelfde lijnen van een file en git weet niet welke versie te houden en welke weg te doen. 

### **Om het te fixen, pull eerst**
```bash
git pull
```
### **Open de files waar er een conflict is. daar zal je jouw veranderingen zien, en de nieuwe veranderingen.**
```bash
<<<<<<<<< HEAD
your changes
=========
incoming changes
```
### **Kies wat je wilt behouden en wat je weg wilt doen en mark als solved, en dan opnieuw:**
```bash
git add .
git commit -m "een bericht met de veranderingen dat je hebt gemaakt"
git push 
```

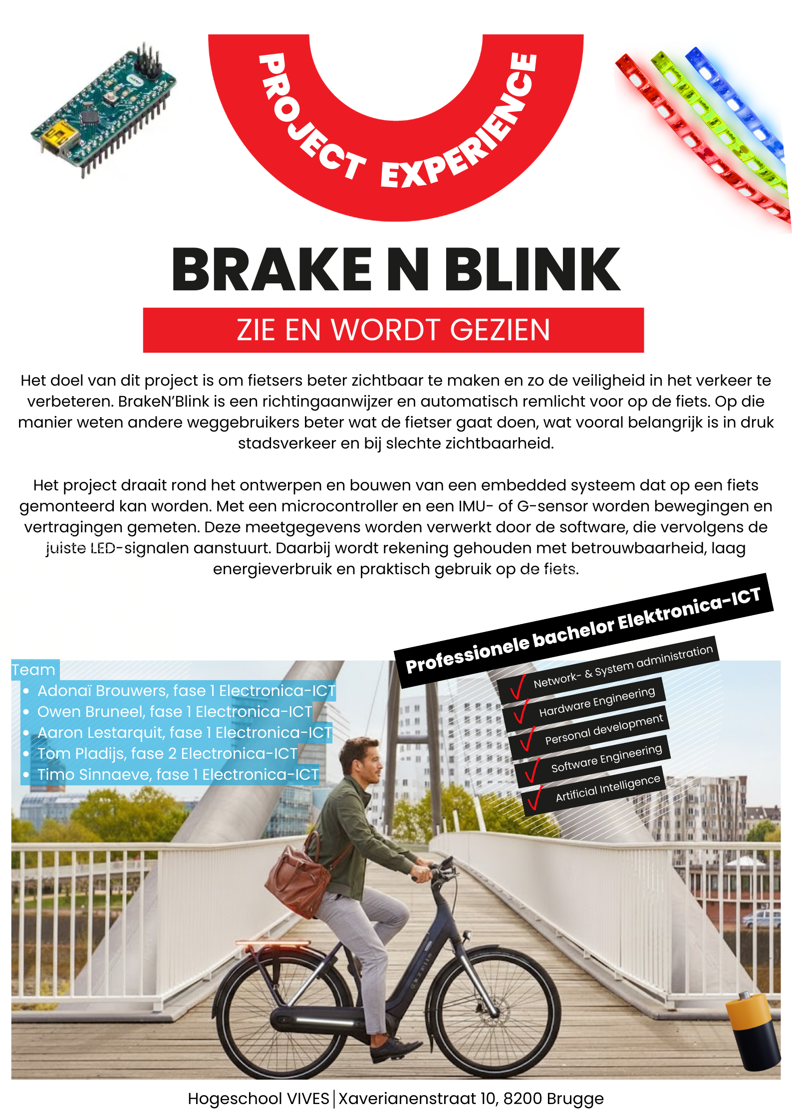
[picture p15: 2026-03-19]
Documentatie/Poster/Poster BrakeNblink.png

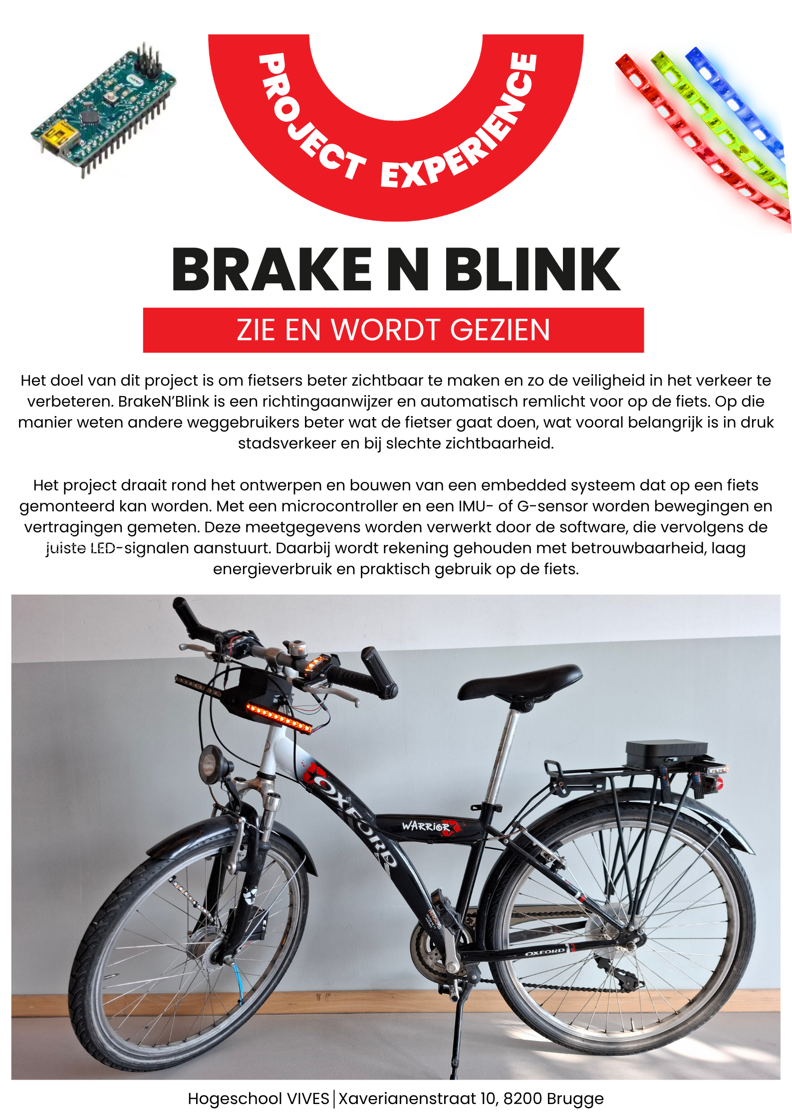
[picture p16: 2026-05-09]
Documentatie/Poster/Poster BrakeNblink v2.png

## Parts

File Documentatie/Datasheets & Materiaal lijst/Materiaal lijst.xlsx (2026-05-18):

Aantal nodig | Datasheets OK | Op school | aantal te kopen | Korte omschrijving | winkel | artikelnummer | Url | bestelling ontvangen | opmerkingen
Basis
2 | Ja | 2 | 1 | Arduino® Nano 33 BLE Sense Rev2 | Farnell (automatisch) | ABX00070 | https://be.farnell.com/arduino/abx00035/nano-33-ble-sense-w-header-dev/dp/3404697 | OK | Er was 1 Arduino defect
2 |  | 0 | 6 | drukknoppen | Farnell (automatisch) | MC32874 | https://be.farnell.com/multicomp/mc32874/tactile-switch-spst-no-0-05a-12v/dp/2543105 | OK
0 | OK | 5 | 0 | Batterijen zelf (LI-ION) 8 | Conrad |  |  | OK
6 | OK | 10 + | 0 | Baterijen AAA | Brico | 8711252098371 | https://www.brico.be/nl/elektra/powerstations-batterijen-opladers/batterijen-batterij-opladers/batterijen/aaa-batterijen/grundig-batterijen-36-stuks-12x-aaa-2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 | OK
2 | OK | 2 | 0 | Baterijen AAA Houder | opencircuit | 11165 | https://opencircuit.nl/product/aaa-x-3-batterij-houder | OK
3 | OK | 3 | 3 | Batterij houders(LI-ION) | opencircuit | 60156 | https://opencircuit.nl/product/battery-holder-2x18650-wire-leads
2 | OK | 5 | 4 | Aan uit switch voeding | Farnell (automatisch) | 2740365 - 62 | https://be.farnell.com/nidec-copal/mfs201n-z/slide-switch-dpdt-1a-125vac-panel/dp/2854848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 | OK
2 | Nee | 0 | 0 | behuizing (3D geprint) |  | PLA - ASA - PETG |  |  | Op school hebben we gekozen voor PLA
1 | Nee | 1 | 0 | software (Arduino) |  |  |  |  | Arduino IDE
6 | Ja | 1 | 0 | Led Strips | Tinytronics | 2055 | https://www.tinytronics.nl/nl/verlichting/led-strips/led-strips/sk6812-digitale-5050-rgbw-led-strip-60-leds-1m
1 | Nee | 1 | 0 | Fiets
0 | Ja | Ok | 0 | BEC (LM2940T-5.0/NOPB) | Farnell (automatisch) |  | https://be.farnell.com/en-BE/texas-instruments/lm2940t-5-0-nopb/ic-v-reg-linear-5v/dp/3122082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
2 | Ja | Ok | 0 | breadboard TW-E40-510 (test boards) | Farnell (automatisch) |  | https://be.farnell.com/en-BE/twin-industries/tw-e40-510/breadboard-solderless-400-tie/dp/2295705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
1 | Ja | Ok | 0 | BC-32629 Wires Female | Farnell (automatisch) |  | https://be.farnell.com/en-BE/bud-industries/bc-32629/jumper-wire-26awg-7-87inch-40pcs/dp/2762507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
1 | Ja | Ok | 1 | BC-32627 wires Male | Farnell (automatisch) |  | https://be.farnell.com/en-BE/bud-industries/bc-32627/jumper-wire-26awg-7-87inch-40pcs/dp/2762506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 | N.v.t
2 | Ja | Ok | 0 | PROTOTYPING BOARD, CEM-3, 100MM X 160MM |  |  | https://be.farnell.com/en-BE/gspk-circuits/gc005-lf/prototyping-board-cem-3-100mm/dp/3263921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
0 | Uit bestelijst exele gehaald 12/02/2026 |  | 3 | TP4056 USB-C Li-ion lader 1A met Li-ion protection circuit | tinytronics | 2151 | https://www.tinytronics.nl/nl/power/bms-en-laders/li-ion-en-li-po/met-protectiecircuit/tp4056-usb-c-li-ion-lader-1a-met-li-ion-protection-circuit | N.v.t
8 | OK |  | 6 | ST-SM 3p connector kabel- 30cm |  | 3580 | https://www.tinytronics.nl/nl/verlichting/led-strips/accessoires/jst-sm-3p-compatible-verlengkabel-30cm | OK
4 | OK |  | 10 | 10-pins vrouwelijke 11 mm hoge stapelbare headerconnector (OT3782) |  |  | https://www.otronic.nl/nl/10-pins-vrouwelijke-11-mm-hoge-stapelbare-headerco.html
4 |  |  | 5 | JST-SM 4p Compatible Verlengkabel - 50cm | tinytronics | 3572 | https://www.tinytronics.nl/nl/verlichting/led-strips/accessoires/jst-sm-4p-compatible-verlengkabel-50cm
0 |  |  | 2 | Pololu 5V, 1A Step-Down Voltage Regulator D24V10F5 | Opencircuit (Online eigen account, NIET per mail) | 2831 | https://opencircuit.be/product/5v-1a-step-down-voltage-regulator-d24v10f5
0 |  |  | 0 | Dresco reflector rood/zwart 112x54mm | Brico | 8711290000000 | https://www.brico.be/nl/fiets-auto-accessoires/fietsmateriaal-accessoires/fietsverlichting-reflectoren/reflectoren/dresco-reflector-rood-zwart-112x54mm/5599370 | Aaron | Focus op verlichting
 |  |  |  | Uitbreiding wielspaken verlichting
1 | Ja | 0 | 1 | Arduino® Nano 33 BLE Sense Rev2 | Conrad | ABX00070 | https://www.conrad.be/nl/p/arduino-abx00070-board-nano-ble-sense-rev2-with-headers-nano-arm-cortex-m4-2740365.html
3 | Ok | 10 + | 0 | AA batterij | Brico | 5400107758739 | https://www.brico.be/nl/elektra/powerstations-batterijen-opladers/batterijen-batterij-opladers/batterijen/aa-batterijen/sencys-aa-batterij-12-stuks-12-gratis/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
1 | OK | 1 | 0 | AA batterij Houder | opencircuit | 10487 | https://opencircuit.nl/product/3-x-aa-batterij-houder
1 | OK | OK | 0 | Aan uit switch voeding | Farnell (automatisch) | 2854848 | https://be.farnell.com/nidec-copal/mfs201n-z/slide-switch-dpdt-1a-125vac-panel/dp/2854848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 | OK
2 | OK |  | 10 | ST-SM 3p connector kabel- 30cm |  | 3580 | https://www.tinytronics.nl/nl/verlichting/led-strips/accessoires/jst-sm-3p-compatible-verlengkabel-30cm | OK
2 | OK |  | 12 | 10-pins vrouwelijke 11 mm hoge stapelbare headerconnector (OT3782) | otronic | OT3782 | https://www.otronic.nl/nl/10-pins-vrouwelijke-11-mm-hoge-stapelbare-headerco.html | Aaron
2 | Nee | 0 | 0 | behuizing (3D geprint) |  | PLA - ASA - PETG |  |  | Op school hebben we gekozen voor PLA
1 | Nee | 1 | 0 | software (Arduino) |  |  |  |  | Arduino IDE
2 | Ja | 1 | 0 | Led Strips | Tinytronics | 2055 | https://www.tinytronics.nl/nl/verlichting/led-strips/led-strips/sk6812-digitale-5050-rgbw-led-strip-60-leds-1m
 |  |  |  | Montage Materiaal
 |  |  | 2 | Kopp kabelbinder UV-bestendig 2,5x100mm zwart 50st. | Brico | 4008220000000 | https://www.brico.be/nl/elektra/bedrading/kabelbinders-houders-accessoires/kabelklemmen/tie-wraps/kopp-kabelbinder-uv-bestendig-2-5x100mm-zwart-50st/5625828 | Aaron
 |  |  | 1 | Isolatietape 19mmx20m zwart | Brico | 4008220000000 | https://www.brico.be/nl/gereedschap-werkplaats/handgereedschap/elektricien-gereedschap/elektrische-isolatietapes/isolatietape-19mmx20m-zwart/1977471 | Aaron
 |  |  | 1 | Tesa Dubbelzijdige tape - Bruin - 5m x 50mm | Brico | 4042450000000 | https://www.brico.be/nl/ijzerwaren/lijmen-tapes-reparatiekits/tapes/dubbelzijdige-tape/tesa-dubbelzijdige-tape-bruin-5m-x-50mm/2753582 | Aaron
 |  |  | 1 | Kopp kabelbinder UV-bestendig 3,6 x 150mm zwart 50 stuks | Brico | 4008220000000 | https://www.brico.be/nl/elektra/bedrading/kabelbinders-houders-accessoires/kabelklemmen/tie-wraps/kopp-kabelbinder-uv-bestendig-3-6-x-150mm-zwart-50-stuks/197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 | Aaron

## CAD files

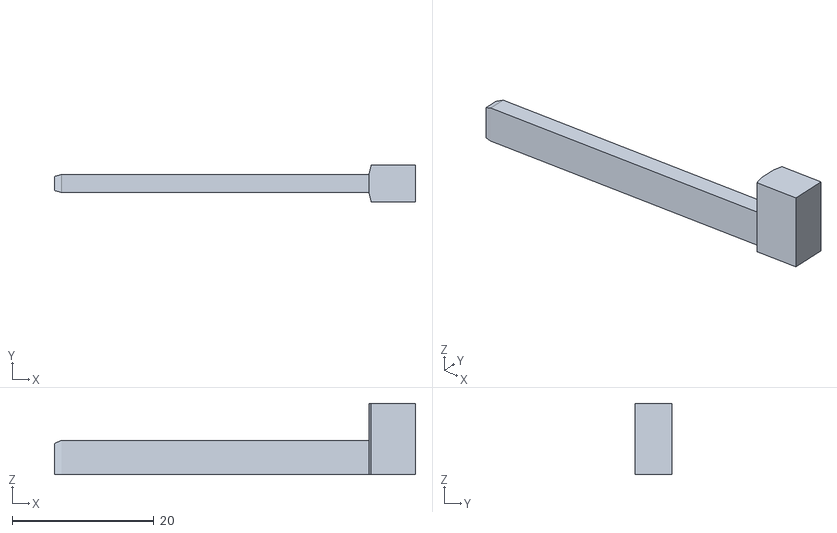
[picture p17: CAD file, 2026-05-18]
3D model behuizing/3D Print Files/Achterkant/achterkant_key.stl
51.0 x 5.16 x 10.1

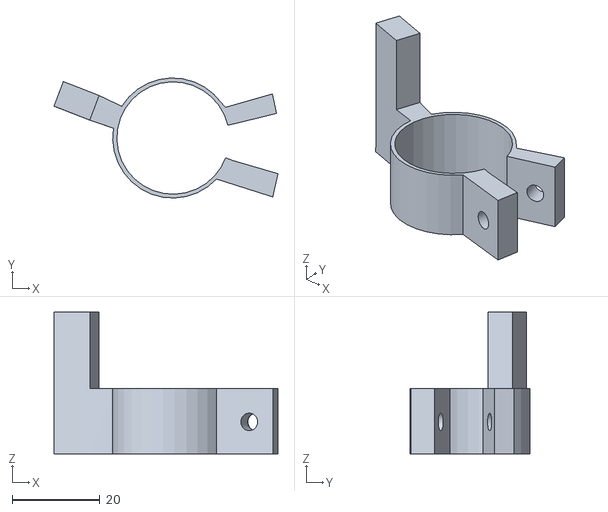
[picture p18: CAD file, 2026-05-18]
3D model behuizing/3D Print Files/Stuur/stuur_mount.stl
51.0 x 27.3 x 32.2

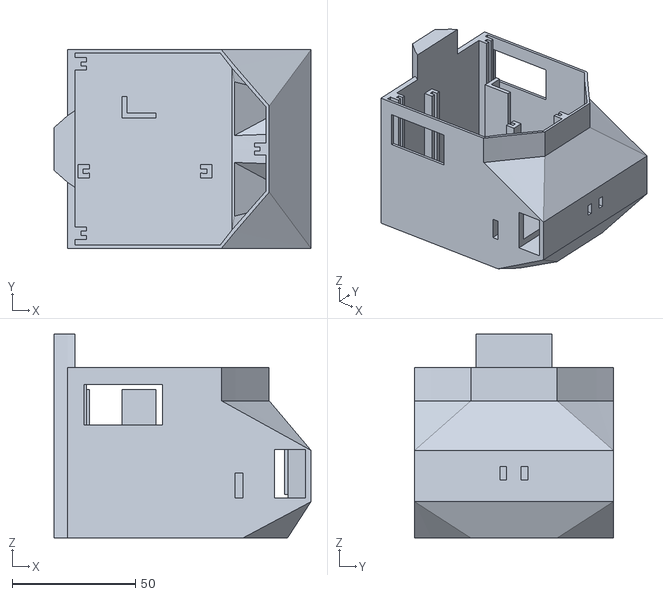
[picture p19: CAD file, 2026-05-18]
3D model behuizing/3D Print Files/Voorkant/voorkant_behuizing.stl
104.4 x 80.7 x 82.9

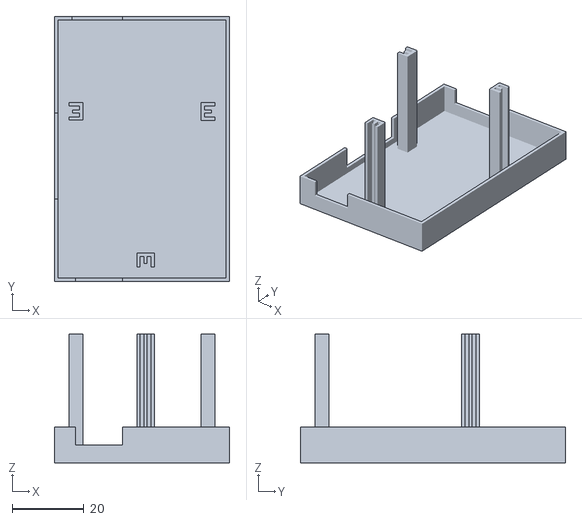
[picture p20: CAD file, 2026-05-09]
3D model behuizing/Uitbreiding/Deksel_Update.stl
49.0 x 74.0 x 36.0

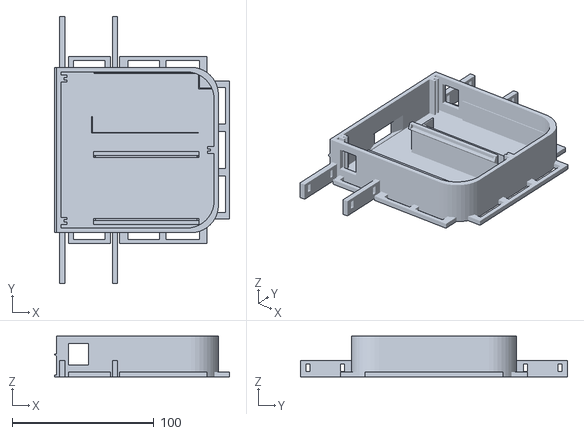
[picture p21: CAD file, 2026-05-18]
3D model behuizing/3D Print Files/Achterkant/achterkant_behuizing.stl
123.5 x 188.4 x 28.7

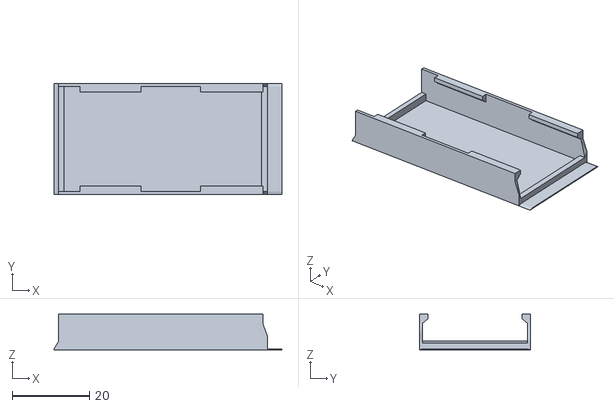
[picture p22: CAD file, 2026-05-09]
3D model behuizing/3D Print Files/Stuur/stuur_led_cover.stl
59.0 x 28.8 x 9.29

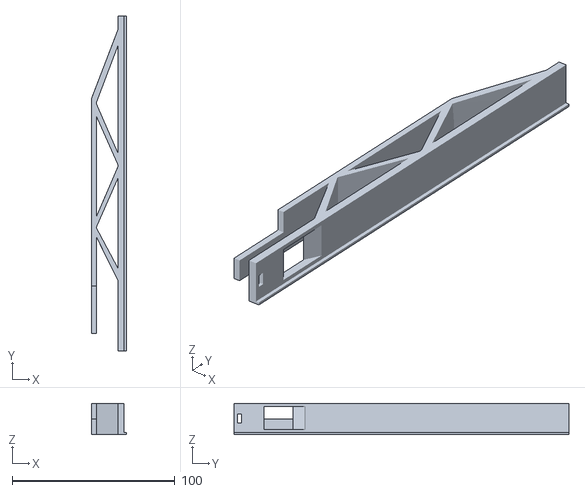
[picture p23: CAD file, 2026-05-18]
3D model behuizing/3D Print Files/Voorkant/voorkant_led_links.stl
21.3 x 205.7 x 19.1

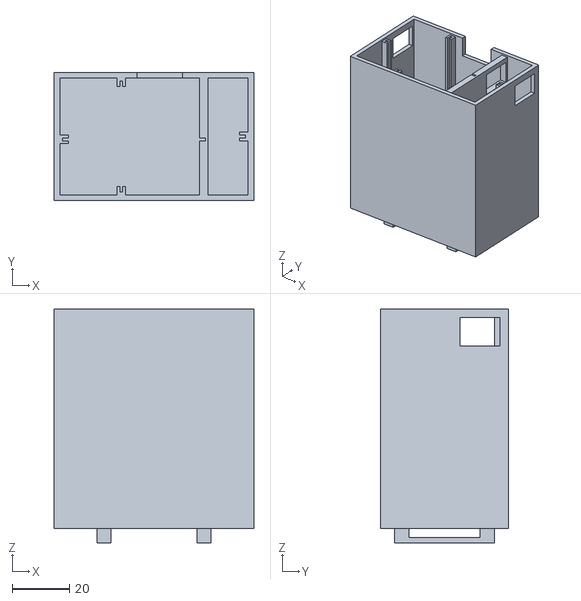
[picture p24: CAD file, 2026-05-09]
3D model behuizing/Uitbreiding/Doos_Update.stl
70.0 x 45.0 x 82.0

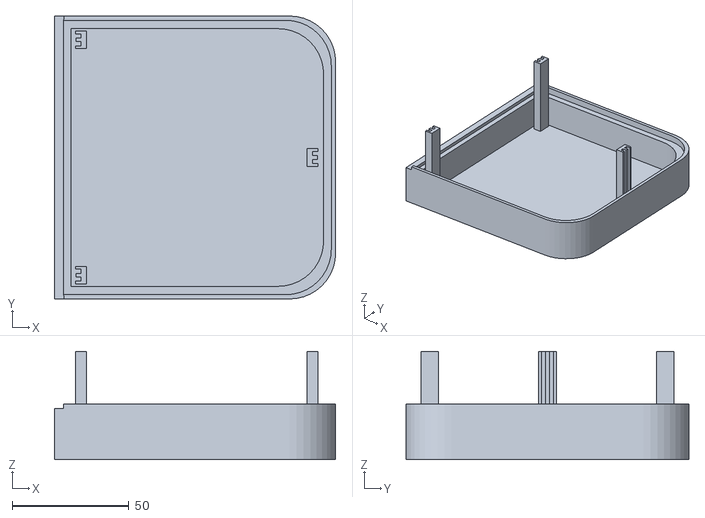
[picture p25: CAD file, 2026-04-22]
3D model behuizing/3D Print Files/Achterkant/achterkant_behuizing_deksel.stl
120.3 x 121.1 x 46.3

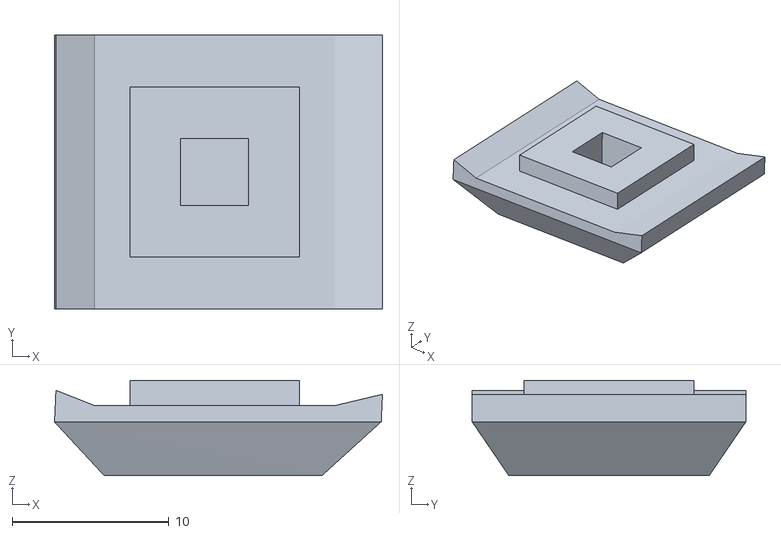
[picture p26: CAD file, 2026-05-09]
3D model behuizing/3D Print Files/Stuur/TPU_stuur_knop_cover.stl
20.9 x 17.5 x 6.08

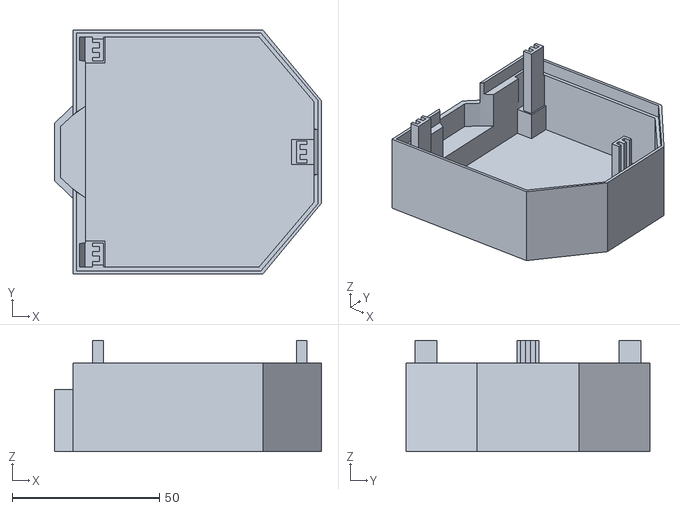
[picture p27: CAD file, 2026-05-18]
3D model behuizing/3D Print Files/Voorkant/voorkant_behuizing_deksel.stl
90.7 x 83.0 x 37.9

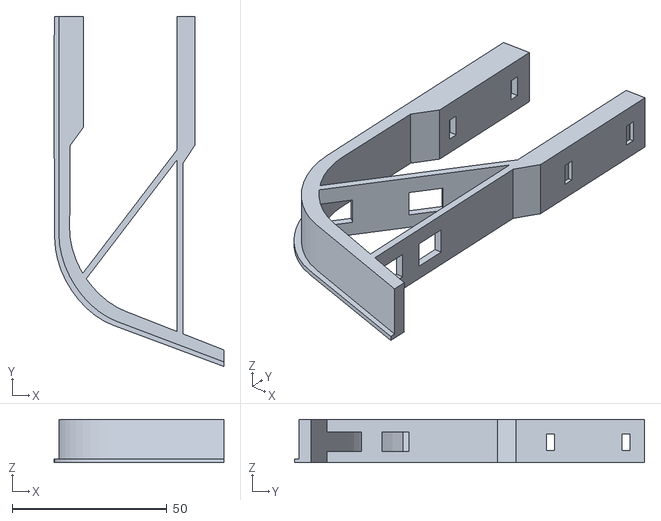
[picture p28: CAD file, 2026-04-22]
3D model behuizing/3D Print Files/Achterkant/achterkant_led_strip_rechts.stl
54.9 x 113.2 x 13.9

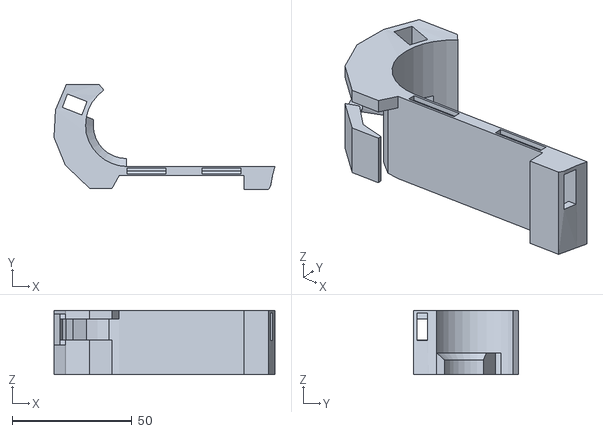
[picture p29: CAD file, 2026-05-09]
3D model behuizing/3D Print Files/Stuur/stuur_behuizing_links.stl
92.4 x 43.9 x 27.0

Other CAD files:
3D model behuizing/Uitbreiding/Deksel.stl
3D model behuizing/3D Print Files/Voorkant/voorkant_led_rechts.stl
3D model behuizing/Uitbreiding/Deksel_Uitbreiding.stl
3D model behuizing/3D Print Files/Achterkant/achterkant_led_strip_links.stl
3D model behuizing/3D Print Files/Stuur/stuur_behuizing_rechts.stl
3D model behuizing/3D Print Files/Voorkant/voorkant_key.stl
3D model behuizing/BrakeNBlink Behuizing.blend
3D model behuizing/Uitbreiding/Deksel.f3d
3D model behuizing/Uitbreiding/Doos.f3d
3D model behuizing/Uitbreiding/Doos_uitbreiding.stl

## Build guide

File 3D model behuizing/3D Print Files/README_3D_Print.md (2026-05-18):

# 3D Print Files - BrakeNBlink Behuizing

Printinstructies de hoofdonderdelen van BrakeNBlink.
Alles is geprint in PLA, behalve "TPU_stuur_knop_cover.stl"
ALles is geprint zonder supports, behalve "stuur_behuizing_links.stl" en "stuur_behuizing_rechts.stl"

---

## Mappenstructuur

```
3D Print Files/
├── README_3D_Print.md        # Dit bestand
├── Voorkant/                 # Behuizing voorkant
│   ├── voorkant_behuizing.stl
│   ├── voorkant_behuizing_deksel.stl
│   ├── voorkant_key.stl
│   ├── voorkant_led_links.stl
│   ├── voorkant_led_rechts.stl
├── Achterkant/               # Behuizing achterkant
│   ├── achterkant_behuizing.stl
│   ├── achterkant_behuizing_deksel.stl
│   ├── achterkant_led_strip_links.stl
│   ├── achterkant_led_strip_rechts.stl
└── Stuur/                    # Stuur
    ├── stuur_behuizing_links.stl     # Heeft support nodig om te printen
    ├── stuur_behuizing_rechts.stl    # Heeft support nodig om te printen
    ├── stuur_mount.stl
    ├── stuur_led_cover.stl
    ├── TPU_stuur_knop_cover.stl      # In TPU geprint

```
---

## Overzicht Onderdelen

Met standaard Bambulab instellingen, zijn dit de geschatte gewichten en printtijden voor elk onderdeel:
(0.20mm hoogte, 2 walls, 200-300mm/s, 15% grid vulling, geen supports)
| Onderdeel | Bestand | Hoeveel | Gewicht (g) | Print tijd |
|---|---|---|---|---|
| Achterkant | `achterkant_behuizing.stl` | 1x | ~74g | 1h56m |
| Achterkant | `achterkant_behuizing_deksel.stl` | 1x | ~64g | 1h46m |
| Achterkant | `achterkant_led_strip_links.stl` | 1x | ~12.3g | 0h27m |
| Achterkant | `achterkant_led_strip_rechts.stl` | 1x | ~12.3g | 0h27m |
| Achterkant | `achterkant_key.stl` | 2x | ~0.7g | 0h12m |
| Stuur | `stuur_behuizing_links.stl` | 1x | ~14.4g | 0h37m |
| Stuur | `stuur_behuizing_rechts.stl` | 1x | ~14.4g | 0h37m |
| Stuur | `stuur_led_cover.stl` | 2x | ~1.8g | 0h15m |
| Stuur | `stuur_mount.stl` | 2x | ~4g | 0h25m |
| Stuur | `TPU_stuur_knop_cover.stl` | 2x | ~1.4g | 0h13m |
| Voorkant | `voorkant_behuizing.stl` | 1x | ~90g | 2h39m |
| Voorkant | `voorkant_behuizing_deksel.stl` | 1x | ~35.4g | 1h0m |
| Voorkant | `voorkant_key.stl` | 2x | ~0.7g | 0h12m |
| Voorkant | `voorkant_led_links.stl` | 1x | ~23.6g | 0h44m |
| Voorkant | `voorkant_led_rechts.stl` | 1x | ~23.6g | 0h44m |

---

## Aanbevolen Printinstellingen

### Algemene Instellingen
```
Laag hoogte:          0.2 mm (standaard)
Vulling:             15-20% (grid patroon)
Snelheid:            (standaard)
Bedtemperatuur:      45°C (PLA) / 60°C (ABS) / 70°C (PETG) / 50°C (TPU)
Nozzle Temperatuur:  220°C (PLA) / 230°C (ABS) / 245°C (PETG) / 210°C (TPU)

```
### Support
```
Type:           tree(auto)
Style:          standaard
Treshhold angle:    30°
Alleen op build plate :    aan
Alleen critische delen:    aan
Verwijder kleine overhang:    aan
```
---

## Gebruikte slicersoftware

#### **Bambu Studio**
- Download: https://bambulab.com/en/download/studio
- Voordelen: Van Bambu Lab, makkelijk voor hun printers

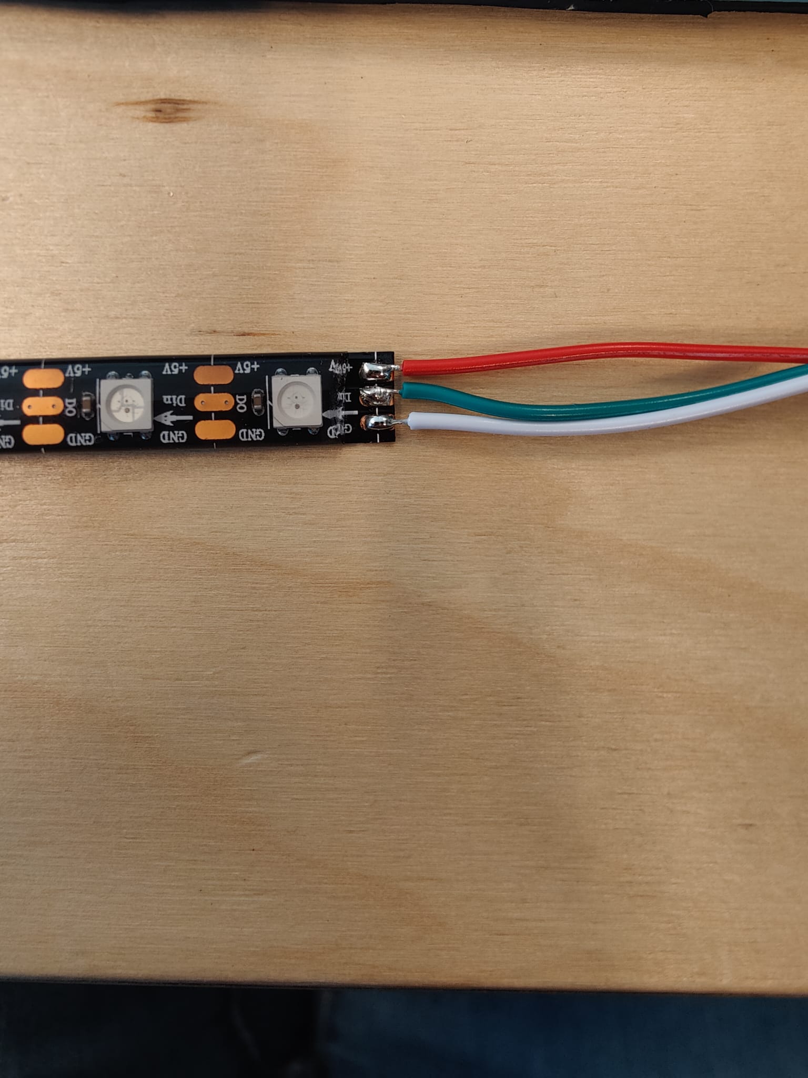
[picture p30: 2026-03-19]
Sociale media/Led's solderen/WhatsApp Image 2026-03-19 at 10.39.29.jpeg

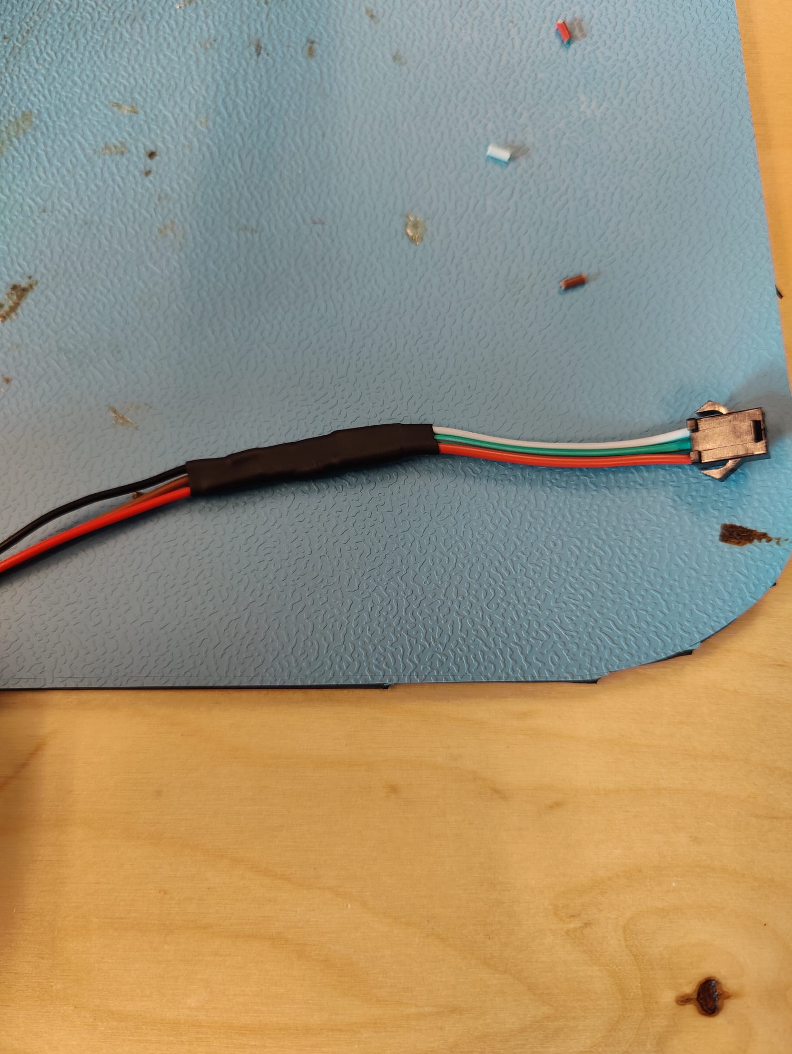
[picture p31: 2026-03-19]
Sociale media/Led's solderen/WhatsApp Image 2026-03-19 at 10.39.36 (2).jpeg

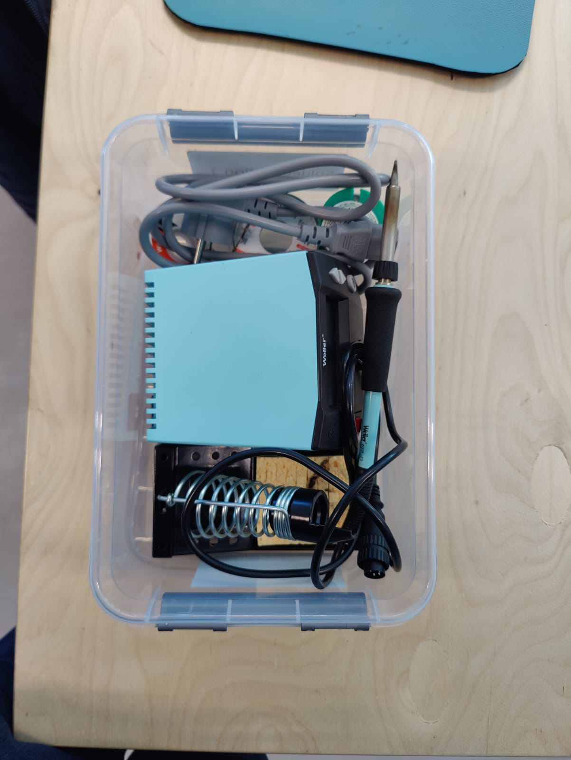
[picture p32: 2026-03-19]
Sociale media/Led's solderen/WhatsApp Image 2026-03-19 at 10.36.53.jpeg

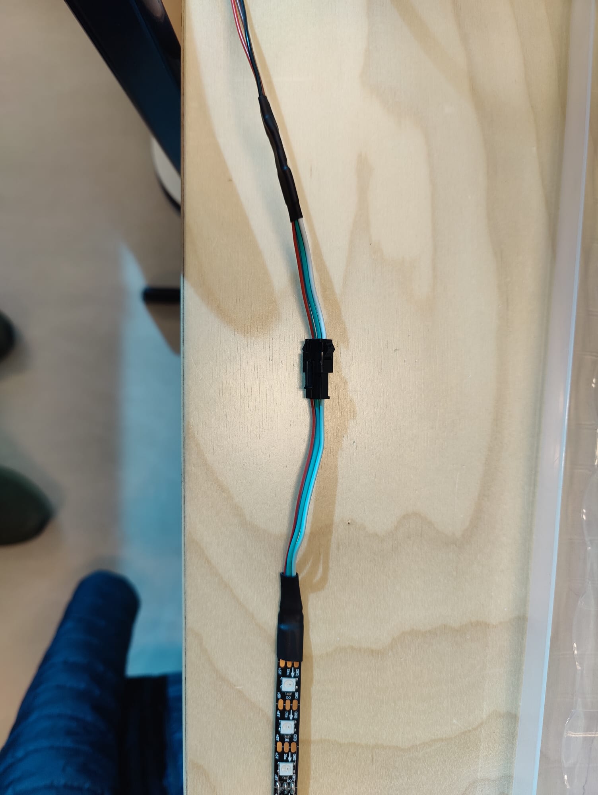
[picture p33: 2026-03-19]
Sociale media/Led's solderen/WhatsApp Image 2026-03-19 at 10.39.36.jpeg

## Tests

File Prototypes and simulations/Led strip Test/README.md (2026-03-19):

#include <Adafruit_NeoPixel.h>
 
#define LED_PIN     2

#define LED_COUNT   4

#define BRIGHTNESS  30
 
Adafruit_NeoPixel strip(LED_COUNT, LED_PIN, NEO_RGB + NEO_KHZ800);
 
uint32_t colors[7];
 
void setup() {

  strip.begin();

  strip.setBrightness(BRIGHTNESS);
 
  colors[0] = strip.Color(255,0,0);     // red

  colors[1] = strip.Color(255,120,0);   // orange

  colors[2] = strip.Color(255,255,0);   // yellow

  colors[3] = strip.Color(0,255,0);     // green

  colors[4] = strip.Color(0,0,255);     // blue

  colors[5] = strip.Color(255,105,180); // pink

  colors[6] = strip.Color(128,0,128);   // purple

}
 
void loop() {
 
  for(int c = 0; c < 7; c++) {
 
    for(int i = 0; i < LED_COUNT; i++) {

      strip.setPixelColor(i, colors[c]);

    }
 
    strip.show();

    delay(500);

  }
 
}

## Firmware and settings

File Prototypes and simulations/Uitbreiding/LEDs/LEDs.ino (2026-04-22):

#include <Adafruit_NeoPixel.h>
#include <Arduino_BMI270_BMM150.h>

#define PIN_A       2
#define PIN_B       3
#define NUMPIXELS  16 // Number of LEDs per strip

Adafruit_NeoPixel stripA(NUMPIXELS, PIN_A, NEO_GRB + NEO_KHZ800);
Adafruit_NeoPixel stripB(NUMPIXELS, PIN_B, NEO_GRB + NEO_KHZ800);

unsigned long previousMillis = 0;
const long interval = 5000; 
int currentMode = 0;
const int totalModes = 8;

void setup() {
  stripA.begin();
  stripB.begin();
  stripA.setBrightness(100);
  stripB.setBrightness(100);
  if (!IMU.begin()) { Serial.println("IMU fail!"); while (1); }
}

void loop() {
  unsigned long currentMillis = millis();

  if (currentMillis - previousMillis >= interval) {
    previousMillis = currentMillis;
    currentMode = (currentMode + 1) % totalModes;
    stripA.clear();
    stripB.clear();
  }

  // Running the modes
  switch (currentMode) {
    case 0:
      dualRainbow(); 
      break;
    case 1:
      solidDual(stripA.Color(255, 0, 0), stripB.Color(0, 0, 255));
      break;
    case 2:
      pingPongEffect(20);
      break;
    case 3:
      travelingPingPong(stripA.Color(0, 255, 255), 20);
      break;
    case 4:
      breatheEffect(0,255,0,20);
      break;
    case 5:
      randomSparkle(stripA.Color(0,0,255),60);
      break;
    case 6:
      discoSparkle(20);
      break;
    case 7:
      imuSpeedMeter();
      break;
  }
}


void dualRainbow() {
  static uint16_t j = 0;
  for(int i=0; i<NUMPIXELS; i++) {
    uint32_t col = Wheel(((i * 256 / NUMPIXELS) + j) & 255);
    stripA.setPixelColor(i, col);
    stripB.setPixelColor(i, col);
  }
  stripA.show();
  stripB.show();
  j++;
}

void solidDual(uint32_t colorA, uint32_t colorB) {
  for(int i=0; i<NUMPIXELS; i++) {
    stripA.setPixelColor(i, colorA);
    stripB.setPixelColor(i, colorB);
  }
  stripA.show();
  stripB.show();
}

void pingPongEffect(int speed) {
  static int pos = 0;
  static int direction = 1;
  static unsigned long lastUpdate = 0;

  if (millis() - lastUpdate > speed) {
    lastUpdate = millis();
    stripA.clear();
    stripB.clear();
    
    for (int i = 0; i < 2; i++) {
      int indexA = (NUMPIXELS - 1) - (pos - i);
      int indexB = (NUMPIXELS - 1) - (pos - i); 

      if (indexA >= 0 && indexA < NUMPIXELS) {
        stripA.setPixelColor(indexA, stripA.Color(255, 0, 0)); 
      }
      
      if (indexB >= 0 && indexB < NUMPIXELS) {
        stripB.setPixelColor(indexB, stripB.Color(0, 255, 0)); 
      }
    }
    
    stripA.show();
    stripB.show();
    
    pos += direction;
    
    if (pos <= 0 || pos >= NUMPIXELS) {
      direction *= -1;
    }
  }
}

// Change 'int speed' to a lower number for FASTER, higher for SLOWER
void travelingPingPong(uint32_t color, int speed) {
  static int pos = 0;
  static int direction = 1;
  static unsigned long lastUpdate = 0;
  int totalLEDs = NUMPIXELS * 2;

  // We use the 'speed' variable here instead of the hardcoded 40
  if (millis() - lastUpdate > speed) { 
    lastUpdate = millis();

    stripA.clear();
    stripB.clear();

    for (int i = 0; i < 2; i++) {
      int activeLED = pos - i;
      
      if (activeLED >= 0 && activeLED < totalLEDs) {
        if (activeLED < NUMPIXELS) {
          // Strip A: REVERSED (Starts at end, moves to start)
          int reverseA = (NUMPIXELS - 1) - activeLED;
          stripA.setPixelColor(reverseA, color);
        } else {
          // Strip B: FORWARD (Starts at start, moves to end)
          int forwardB = activeLED - NUMPIXELS;
          stripB.setPixelColor(forwardB, color);
        }
      }
    }

    stripA.show();
    stripB.show();

    pos += direction;

    if (pos <= 0 || pos >= totalLEDs) {
      direction *= -1;
    }
  }
}

void breatheEffect(uint8_t r, uint8_t g, uint8_t b, int speed) {
  static unsigned long lastUpdate = 0;
  static int brightness = 0;
  static int direction = 1;

  if (millis() - lastUpdate > speed) {
    lastUpdate = millis();

    // Use math to create a smooth brightness curve
    float intensity = (sin(millis() / 500.0) + 1) * 127; 
    uint32_t color = stripA.Color((r * intensity) / 255, (g * intensity) / 255, (b * intensity) / 255);

    for (int i = 0; i < NUMPIXELS; i++) {
      stripA.setPixelColor(i, color);
      stripB.setPixelColor(i, color);
    }
    stripA.show();
    stripB.show();
  }
}

void randomSparkle(uint32_t color, int speed) {
  static unsigned long lastUpdate = 0;

  // Use the 'speed' variable (e.g., 100) to control the interval
  if (millis() - lastUpdate > speed) {
    lastUpdate = millis();

    // OPTIONAL: Dim existing LEDs slightly to create a "fading" trail
    // If you want them to just pop on and off, use stripA.clear() instead.
    for(int i=0; i<NUMPIXELS; i++) {
        stripA.setPixelColor(i, 0); // Clear Strip A
        stripB.setPixelColor(i, 0); // Clear Strip B
    }

    // Pick a random LED index (0 to NUMPIXELS-1)
    int randomLED_A = random(NUMPIXELS);
    int randomLED_B = random(NUMPIXELS);

    // Light them up!
    stripA.setPixelColor(randomLED_A, color);
    stripB.setPixelColor(randomLED_B, color);

    stripA.show();
    stripB.show();
  }
}

void discoSparkle(int speed) {
  static unsigned long lastUpdate = 0;

  if (millis() - lastUpdate > speed) {
    lastUpdate = millis();

    // Create a random color
    uint32_t randomColor = stripA.Color(random(255), random(255), random(255));

    int randomLED_A = random(NUMPIXELS);
    int randomLED_B = random(NUMPIXELS);

    stripA.setPixelColor(randomLED_A, randomColor);
    stripB.setPixelColor(randomLED_B, randomColor);

    stripA.show();
    stripB.show();
  }
}

void imuSpeedMeter() {
  static float smoothAccel = 1.0;
  float currentAccel = getAcceleration();
  
  // Simple low-pass filter to make the lights less "jittery"
  smoothAccel = (smoothAccel * 0.9) + (currentAccel * 0.1);

  // Map the acceleration to the number of LEDs
  // 1.0 is sitting still, 2.0+ is moving/shaking
  int numLedsToLight = map(smoothAccel * 100, 100, 250, 0, NUMPIXELS);
  numLedsToLight = constrain(numLedsToLight, 0, NUMPIXELS);

  stripA.clear();
  stripB.clear();

  for (int i = 0; i < numLedsToLight; i++) {
    // Color changes from Green to Red as it fills up
    uint32_t color = Wheel(map(i, 0, NUMPIXELS, 85, 0)); 
    stripA.setPixelColor(i, color);
    stripB.setPixelColor(i, color);
  }

  stripA.show();
  stripB.show();
}

uint32_t Wheel(byte WheelPos) {
  if(WheelPos < 85) return stripA.Color(WheelPos * 3, 255 - WheelPos * 3, 0);
  else if(WheelPos < 170) {
    WheelPos -= 85;
    return stripA.Color(255 - WheelPos * 3, 0, WheelPos * 3);
  } else {
    WheelPos -= 170;
    return stripA.Color(0, WheelPos * 3, 255 - WheelPos * 3);
  }
}

float getAcceleration() {
  float ax, ay, az;
  if (IMU.accelerationAvailable()) {
    IMU.readAcceleration(ax, ay, az);
    // Calculate total magnitude of acceleration
    return sqrt(ax * ax + ay * ay + az * az);
  }
  return 1.0; // Default gravity is ~1G
}

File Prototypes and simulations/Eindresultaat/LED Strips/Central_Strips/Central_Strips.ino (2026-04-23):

#include <ArduinoBLE.h>
#include <Adafruit_NeoPixel.h>

const int buttonPin = 2;
const int buttonPin2 = 3;

#define PIN_LEFT    4
#define PIN_RIGHT   5
#define PIN_LEFT_AUDI 6
#define PIN_RIGHT_AUDI 7
#define NUM_LEDS    12

Adafruit_NeoPixel stripL(NUM_LEDS, PIN_LEFT,  NEO_GRB + NEO_KHZ800);
Adafruit_NeoPixel stripR(NUM_LEDS, PIN_RIGHT, NEO_GRB + NEO_KHZ800);
Adafruit_NeoPixel stripLA(NUM_LEDS, PIN_LEFT_AUDI,  NEO_GRB + NEO_KHZ800);
Adafruit_NeoPixel stripRA(NUM_LEDS, PIN_RIGHT_AUDI, NEO_GRB + NEO_KHZ800);

uint32_t orange = stripL.Color(255, 60, 0);
uint32_t red    = stripL.Color(255, 0, 0);
uint32_t black  = stripL.Color(0, 0, 0);

const char* deviceServiceUuid = "19b10000-e8f2-537e-4f6c-d104768a1214";
const char* deviceServiceCharacteristicUuid = "19b10001-e8f2-537e-4f6c-d104768a1214";

unsigned long lastDebounceTime1 = 0;
unsigned long lastDebounceTime2 = 0;
unsigned long debounceDelay = 150;

int lastButtonState = HIGH;
int lastButtonState2 = HIGH;

const int connectionLed = 5;

bool blinkLinker = false;
bool blinkRechter = false;
unsigned long lastBlinkTime = 0;
const int blinkInterval = 450;
bool ledToggleState = false;

int audiIndex = 0;
unsigned long lastAudiStep = 0;
const int audiSpeed = 35;

void setup() {
  Serial.begin(9600);
  pinMode(buttonPin, INPUT_PULLUP);
  pinMode(buttonPin2, INPUT_PULLUP);
  pinMode(connectionLed, OUTPUT);
  digitalWrite(connectionLed, LOW);
  stripL.begin(); stripR.begin();
  stripL.show();  stripR.show();

  // bluetooth starten
  if (!BLE.begin()) {
    Serial.println("- BLE failed!");
    while (1);
  }
  
  BLE.scanForUuid(deviceServiceUuid);
  Serial.println("Scanning for Peripheral...");
}
// meer bluetooth
void loop() {
  BLEDevice peripheral = BLE.available();

  if (peripheral) {
    if (peripheral.localName() == "Nano 33 BLE Peripheral") {
      BLE.stopScan();
      controlPeripheral(peripheral);
      BLE.scanForUuid(deviceServiceUuid);
    }
  }
}
// meer bluetooth
void controlPeripheral(BLEDevice peripheral) {
  if (!peripheral.connect()) return;

  digitalWrite(connectionLed, HIGH);
  if (!peripheral.discoverAttributes()) {
    peripheral.disconnect();
    return;
  }

  BLECharacteristic dataChar = peripheral.characteristic(deviceServiceCharacteristicUuid);

  // Wat er moet gebeuren als ze verbonden zijn
  while (peripheral.connected()) {
    // Audi licht logica
    if (blinkLinker || blinkRechter) {
      if (millis() - lastAudiStep >= audiSpeed) {
        lastAudiStep = millis();
        audiIndex++;
        if (audiIndex >= NUM_LEDS) audiIndex = 0;
      }
    } else {
      audiIndex = 0;
    }

    // Knipperlicht logica
    if (millis() - lastBlinkTime >= blinkInterval) {
    lastBlinkTime = millis();
    ledToggleState = !ledToggleState;
    if (ledToggleState) audiIndex = 0; 
    }

    if (blinkLinker) {
      fillStrip(stripL, ledToggleState ? orange : black);
      fillStrip(stripR, black);
    
      updateAudiBlinker(stripLA, true);
      updateAudiBlinker(stripRA, false);
    } 
    else if (blinkRechter) {
      fillStrip(stripR, ledToggleState ? orange : black);
      fillStrip(stripL, black);
    
      updateAudiBlinker(stripRA, true);
      updateAudiBlinker(stripLA, false);
    }
    else {
      fillStrip(stripL, black);
      fillStrip(stripR, black);
      updateAudiBlinker(stripLA, false);
      updateAudiBlinker(stripRA, false);
    }

    int reading1 = digitalRead(buttonPin);
    int reading2 = digitalRead(buttonPin2);

    // Drukknoppen logica
    if (reading1 == LOW && (millis() - lastDebounceTime1 > debounceDelay)) {
      dataChar.writeValue((byte)1);
      blinkLinker = !blinkLinker; if (blinkLinker) blinkRechter = false;
      lastDebounceTime1 = millis();
    }

    if (reading2 == LOW && (millis() - lastDebounceTime2 > debounceDelay)) {
      dataChar.writeValue((byte)3); 
      blinkRechter = !blinkRechter; if (blinkRechter) blinkLinker = false;
      lastDebounceTime2 = millis();
    }
  }

  // Reset als niet connected
  blinkRechter = false;
  blinkLinker = false;
  fillStrip(stripL, black);
  fillStrip(stripR, black);
  fillStrip(stripLA, black);
  fillStrip(stripRA, black);
}

// Kleur functie
void fillStrip(Adafruit_NeoPixel &s, uint32_t color) {
  for(int i=0; i<NUM_LEDS; i++) {
    s.setPixelColor(i, color);
  }
  s.show();
}
// Audi functie
void updateAudiBlinker(Adafruit_NeoPixel &strip, bool active) {
  if (!active) {
    for(int i=0; i<NUM_LEDS; i++) strip.setPixelColor(i, black);
  } else {
    // Light up LEDs from 0 to audiIndex
    for(int i=0; i<NUM_LEDS; i++) {
      strip.setPixelColor(i, (i <= audiIndex) ? orange : black);
    }
  }
  strip.show();
}

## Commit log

2026-02-05 materiaal exele
    [materiaal overzicht lijst.xlsx]
2026-02-05 arduino mapje
2026-02-05 test exele
    [materiaal overzicht lijst.xlsx]
2026-02-05 link naar IMU data
2026-02-05 info project readme.md
    [materiaal overzicht lijst.xlsx]
2026-02-05 materiaal lijst update
    [materiaal overzicht lijst.xlsx]
2026-02-05 LED strip readme aangemaakt
2026-02-05 Update LED Strips.md
2026-02-07 submap Prototypes and simulations
2026-02-07 test prototype Arduino nano 2 leds
2026-02-12 Add Arduino PIN OUT section to README
    Added Arduino PIN OUT section with an image.
2026-02-12 README.md aangemaakt voor de knoppen en werking ervan
2026-02-12 map overzichten & toevoegen project canvas
    [Materiaal lijst.xlsx, Project Canvas BrakeN'Blink.xlsx]
2026-02-12 update Project canvas
    [Project Canvas BrakeN'Blink.xlsx]
2026-02-12 rename Arduino nano 2 leds --> Readme
2026-02-12 Enhance README with button details and wiring
    Updated the README to provide detailed descriptions of the buttons used for direction indicators, including wiring and disadvantages of each type.
2026-02-12 Update README with corrected switch button details
    Corrected wiring layout and description for the switch button.
2026-02-12 materiaal overzicht & uitbreiding map datasheets
    [Materiaal lijst.xlsx]
2026-02-12 prototype 1
2026-02-12 materiaal lisjt update & toevoegen datasheets
    [Materiaal lijst.xlsx]
2026-02-12 materiaal lijst update + nieuwe datasheets + invullen aankoop lijst
    [Materiaal lijst.xlsx]
2026-02-12 Update LED strip documentation with pin naming
2026-02-12 Add image and specifications for LED SK8612 strip
2026-02-12 bestellijst aangevuld & pdf's van componenten aangevuld
    [Materiaal lijst.xlsx]
2026-02-26 Update magteriaal lijst geleverde goederen - connector kabels
    [Materiaal lijst.xlsx]
2026-02-26 Datasheets & Materiaal lijst mappen namen update's & onvangen componenten binnen nemen in materiaal lijst
    [Materiaal lijst.xlsx]
2026-02-26 10-pins vrouwelijke 11 mm hoge stapelbare headerconnector (OT3782) in materiaal lijst gezet
    [Materiaal lijst.xlsx]
2026-02-26 Rename Poster BrakeNblink (1).png to Poster BrakeNblink.png
2026-03-04 Sprekers notas & eerste top down schema
    [Materiaal lijst.xlsx]
2026-03-05 Led strip Test prototype
2026-03-19 Sociale media map & opmaak led's foto's & eerste protype testing op de fiets
2026-03-19 prototype behuizing geprint, nu bezig met finale design
    [Materiaal lijst.xlsx, fietsstuur clamp.stl, fietsstuur knop + led.stl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]
2026-03-19 TDS schema's eerste prototype
2026-03-26 tweede versie behuizing
    [knop.3mf]
2026-03-26 Materiaal overzicht lijst aangevuld met alle componenten
    [Materiaal lijst.xlsx]
2026-03-26 architectuur document Start
    [Architectuur document.xlsx]
2026-03-26 social media tweede prototype op de fiets ontbrekende behuizingen
2026-04-22 nieuwere versies van behuizing, meer plaats voor LED strips en een paar kleine problemen opgelost + ge-exporteerd als STL om te kunnen printen
    [achterkant_behuizing.stl, achterkant_behuizing_deksel.stl, achterkant_led_strip_links.stl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]
2026-04-23 Eerste versie van de uitbreiding in het voorwiel
    [Deksel_Uitbreiding.stl, Doos_uitbreiding.stl]
2026-04-30 Deksel behuizing uitbreiding 0.1mm uitgebreid
    [Deksel.stl]
2026-04-30 Update battery information in README
2026-04-30 readme toegevoegd voor behuizing en stl files met AI
    [Deksel.stl, Deksel_Uitbreiding.stl, Doos_uitbreiding.stl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]
2026-04-30 Afbeeldingen toegevoegd aan de gebruikershandleiding.
2026-04-30 fusion files voor uitbreiding
    [Deksel.f3d, Doos.f3d]
2026-04-30 Update README met details en delen van AI weggedaan
    Expanded project overview and detailed assembly instructions.
2026-04-30 chore: mappenstructuur + foto’s en presentatie voor finale presentatie toegevoegd
    Structuur en bestanden toegevoegd voor een overzichtelijke eindpresentatie.
2026-04-30 files hernoemd en bestand structuur in de blender file verbeterd
    [BrakeNBlink Behuizing.blend, Deksel.f3d, Doos.f3d]
2026-05-07 hernoemd ORMANÄS led-strip image omdat het te lang was
2026-05-07 Foto in ReadME aangepast.
    [Deksel_Update.stl, Doos_Update.stl]
2026-05-09 alle 3d print stl files ge-update
    [BrakeNBlink Behuizing.blend, TPU_stuur_knop_cover.stl, fietsstuur clamp.stl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]
2026-05-18 blender readme en 3d print readme bestanden aangepast + nieuwe stl print bestanden voor sommige onderdelen
    [BrakeNBlink Behuizing.blend, achterkant_behuizing.stl, stuur_mount.stl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]
2026-05-18 smalle aanpassingen en verbeteringen gemaakt in print readme files
    [BrakeNBlink Behuizing.blend, achterkant_key.stl]
2026-05-18 Link naar ondrive gemaakt voor de grote bestanden
2026-05-18 Laatste controle materiaal lijst : overzicht document OK
    [Materiaal lijst.xlsx]
2026-05-18 Architectuur Document : Laatste controle & aanpassing gebuik van batterijen van lipo naar AA en AAA's
2026-05-19 TDS schema's aangepast: Powerpoint vriendelijk gemaakt door wwaarders te verwijderen en ingevoegd in powerpoint
